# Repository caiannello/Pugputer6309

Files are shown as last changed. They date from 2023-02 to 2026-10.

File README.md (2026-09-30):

## Introduction
--------------------------------------------------------------------------------
```
WELCOME TO THE PUGPUTER 6309 PROJECT !!!

The Pugputer is a little labor of love, made as a tribute to the 
early home computers of the 1980's.  

It is based on the Hitachi HD63C09 CPU- an upgraded licensed clone of the
venerable Motorola 6809, and uses vintage parts where appropriate. 
(Except RAM chips, which are plentiful and affordable these days, and a modern 
microcontroller to handle SD card and GPIO.)

Projects in the Hardware directory: 
  (Using CADSOFT EAGLE 4.16r2)

  6309 CPU Card -       HD63C09P CPU, R65C51P2 UART, 1MB RAM, 32K ROM, RTC
                        (Mem expandable to 4MB) 
  Backplane -           Five card slots, tombstone style 
  V9958 Video -         Same graphics chip as the MSX 2+ home computer 
                        Optional OPL3 synthesizer module (YMF262)
  VIA_SD_PSUP -         SD Card, SPI, I2C, ADC, parallel port, and power supply.
  3 MB RAM Expans. -    Gives the Pugputer more memory than actual pugs. 
  all-in-one -          Combines all of the above on one 10.6" x 3.5" board

Projects in the Software Directory:  (All are work-in-progress, stay tuned.) 
  (Using LWTOOLS/LWASM 4.20 for the 6309 assembly stuff)

  6309 Extended Basic -   Microsoft, Walter K. Zydhek, Grant Searle,
                          Tom Circuit, and me
  boot -                  Minimal bootloader (Also unfinished, but coming soon!)
  Pugmon -                ML Monitor (Far from complete)
  Demos -                 graphics and sound examples in Assembly and BASIC

3D Models 
  (Using Trimble SketchUp MAKE 17.2.2555 for Windows 64-bit )
(Nice renders using Indigo Renderer by Glare Technologies)

```
## There's now a (vibe-coded) Emulator!
[Pugputer6309_Emulator](https://github.com/caiannello/Pugputer6309_Emulator)
It's got 1MB RAM, UART, 4K BIOS, FAT16 SD Card, RP2350-based Graphics Card, OPL3 Sound, DOS-like command shell, 
and on the SD card is a Text Editor, Assembler, Linker, and a version of Microsoft Extended BASIC 6809 that's 
been expanded with DISK support patterned on GW-BASIC, graphics and sprites, and the ON ERROR statement.
There's also some demos which play OPL3 music and demonstrate graphics capabilities.

On my PC, the emulator currently runs 92x faster than the actual hardware. Going to need to add throttling. 

You can interact with it from command prompt, a real Glass TTY at 19.2Kbaud, or if using the com0com NULL-modem 
driver for Windows, a terminal program. There's also a demo folder on the SD card that plays a couple VGM songs 
and demos some graphics. Excited to get the new utils/OS running on the real HW!  Also, note the lack of 
V9958 video. Going to go with the RP2350 instead, since it's much more capable and easy to use, and the V9958 
is getting more scarce and expensive. Using a modern MCU does bother me, but not as much as using an FPGA or
an inferior rare chip.

## Gallery

Graphics from SquareSoft's Seiken Densetsu 3 for Super NES ([Source code](https://github.com/caiannello/Pugputer6309/blob/main/Software/6309/Demos/mana_tilemap.asm))
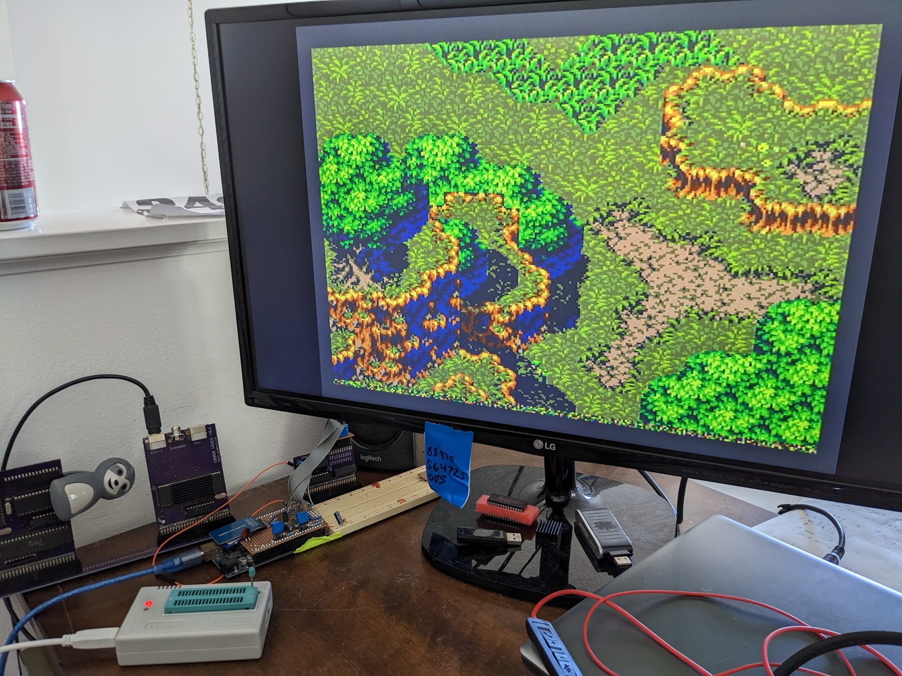
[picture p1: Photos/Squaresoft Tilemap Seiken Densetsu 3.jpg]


Microsoft Extended BASIC for 6809, modified by Grant Searle, Tom Circuit, and me ([Source code](https://github.com/caiannello/Pugputer6309/tree/main/Software/6309/MS%20Extended%20BASIC))
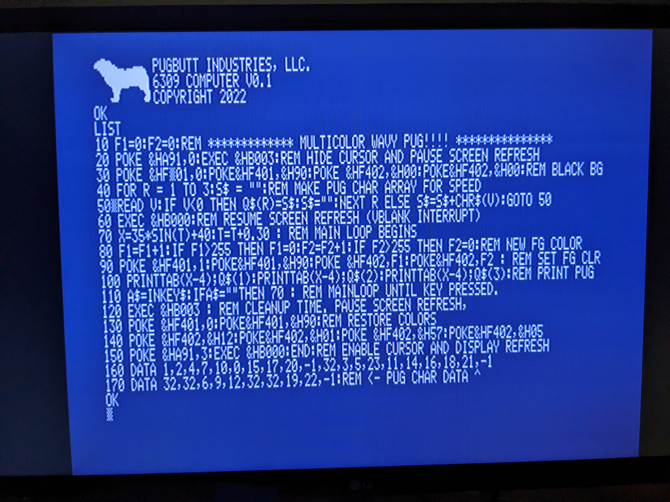
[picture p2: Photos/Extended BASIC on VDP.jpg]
basic


This one uses the library from the ancient [Motorola MC6839 FLOATING POINT ROM!](http://jefftranter.blogspot.com/2019/04/a-6809-single-board-computer-mc6839.html) ([Source code](https://github.com/caiannello/Pugputer6309/blob/main/Software/6309/Demos/mandelbrot.asm))
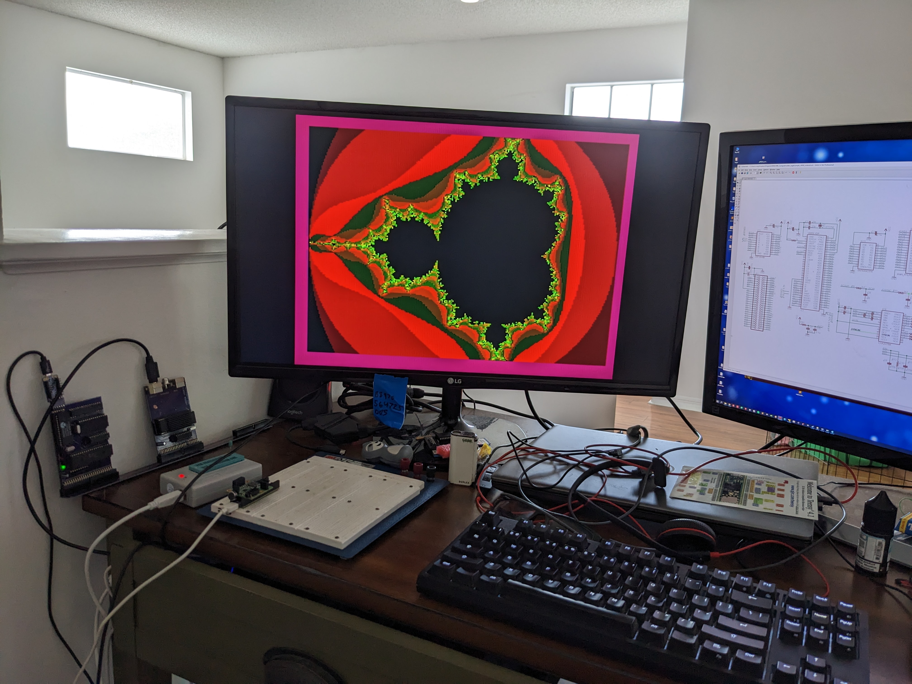
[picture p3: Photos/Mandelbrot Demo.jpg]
mandelbrot


[PugMon](https://github.com/caiannello/Pugputer6309/tree/main/Software/6309/Pugmon)
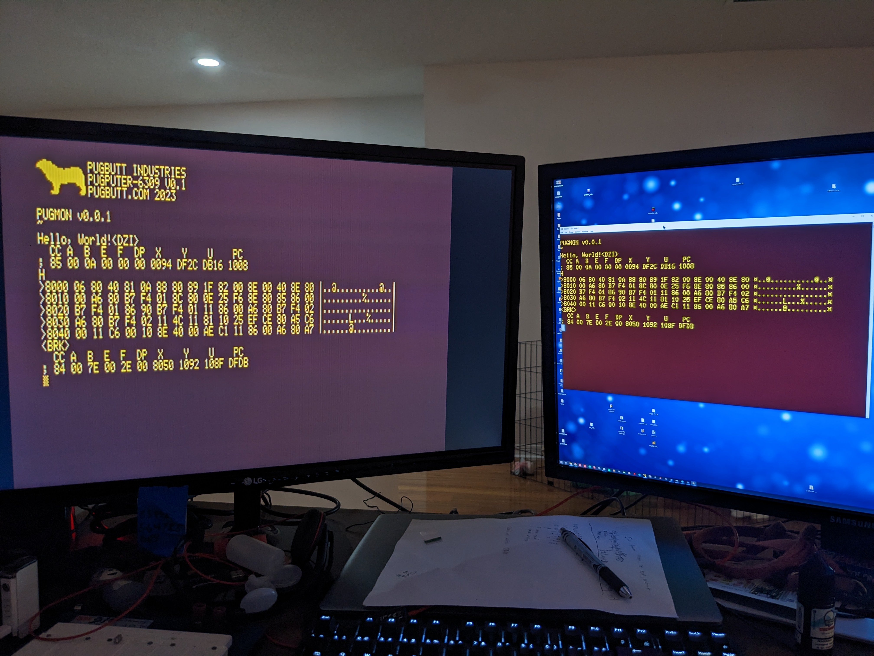
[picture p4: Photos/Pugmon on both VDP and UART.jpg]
pugmon


Lily from a local pond, converted to the V9958's high-color YJK mode using a Python utility. Please ignore my dog's toothpaste and "toothbrush". Please also ignore the ugly DRAM sidecar on the video card, I think the SRAM problem has been found. (I used a CMOS instead of a CMOS TTL latch.)  

([Source code](https://github.com/caiannello/Pugputer6309/blob/main/Software/6309/Demos/lily_highcolor_yjk.asm))([Conversion Utility](https://github.com/caiannello/Pugputer6309/blob/main/Software/dev_utils/image_conversion/conv_yjk.py))
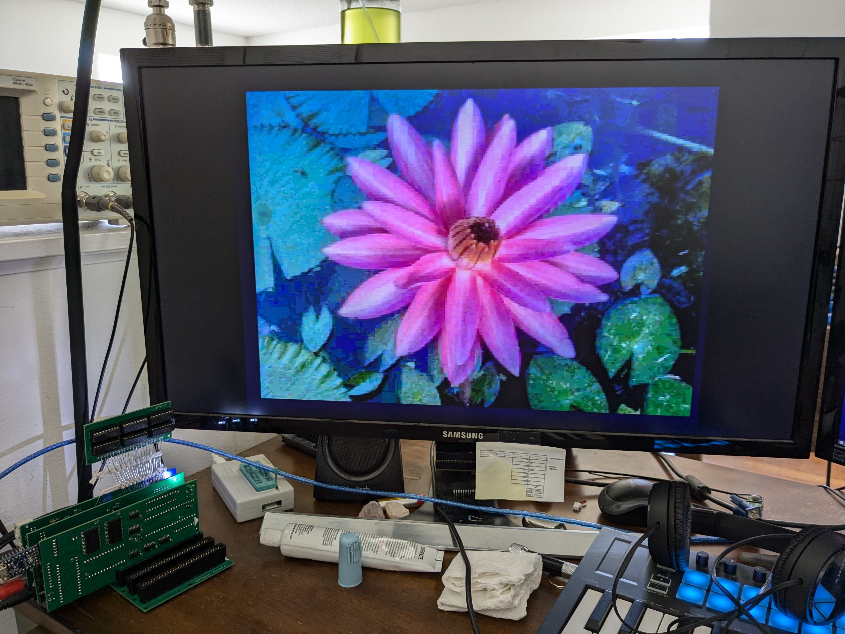
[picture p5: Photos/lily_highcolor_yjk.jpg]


Experimental Pugputer startup screen + jingle by ([Bisqwit](https://https://bisqwit.iki.fi/)!

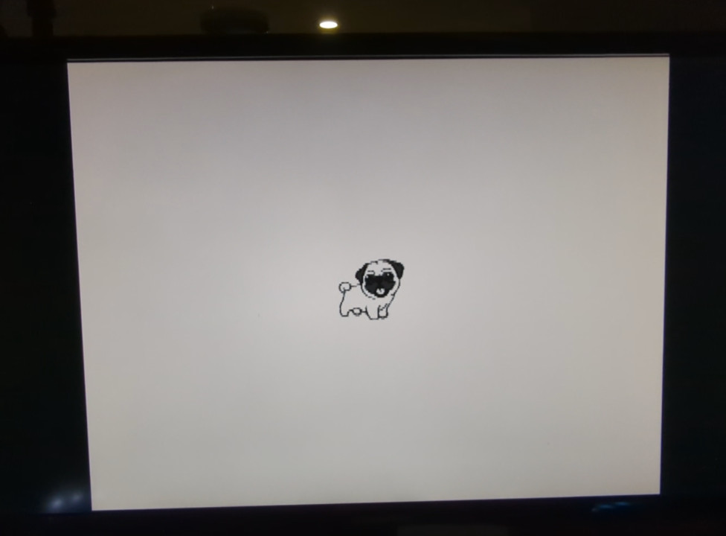
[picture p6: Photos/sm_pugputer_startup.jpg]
Watch Video


### CPU Card v2 (Card cage design)

CPU Card with 1MB RAM and UART
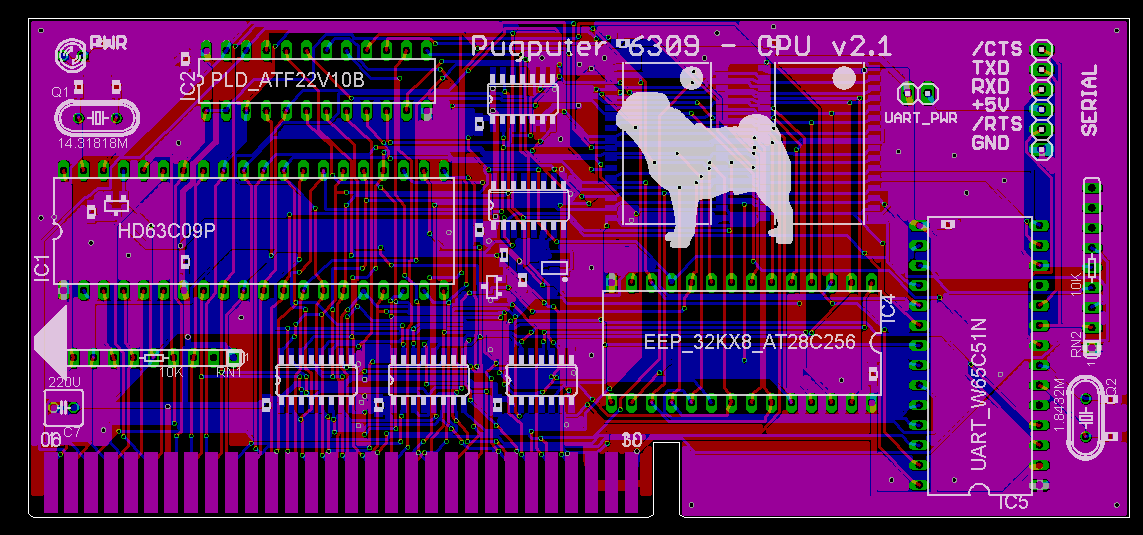
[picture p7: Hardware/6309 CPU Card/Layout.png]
layout


Backplane
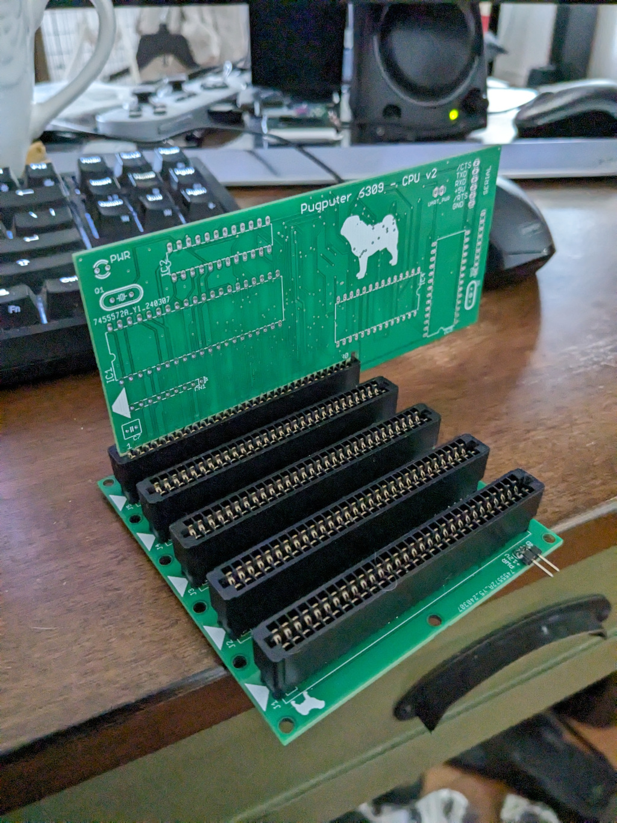
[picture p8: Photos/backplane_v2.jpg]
backplane v2


### All-In-One Motherboard

6309 CPU @ 3.57MHz, Serial Port, Real-time clock, 4MB RAM, SD Card, Arduino MCU, V9958 Video, OPL3 Sound  (Board size 11" x 3.5")
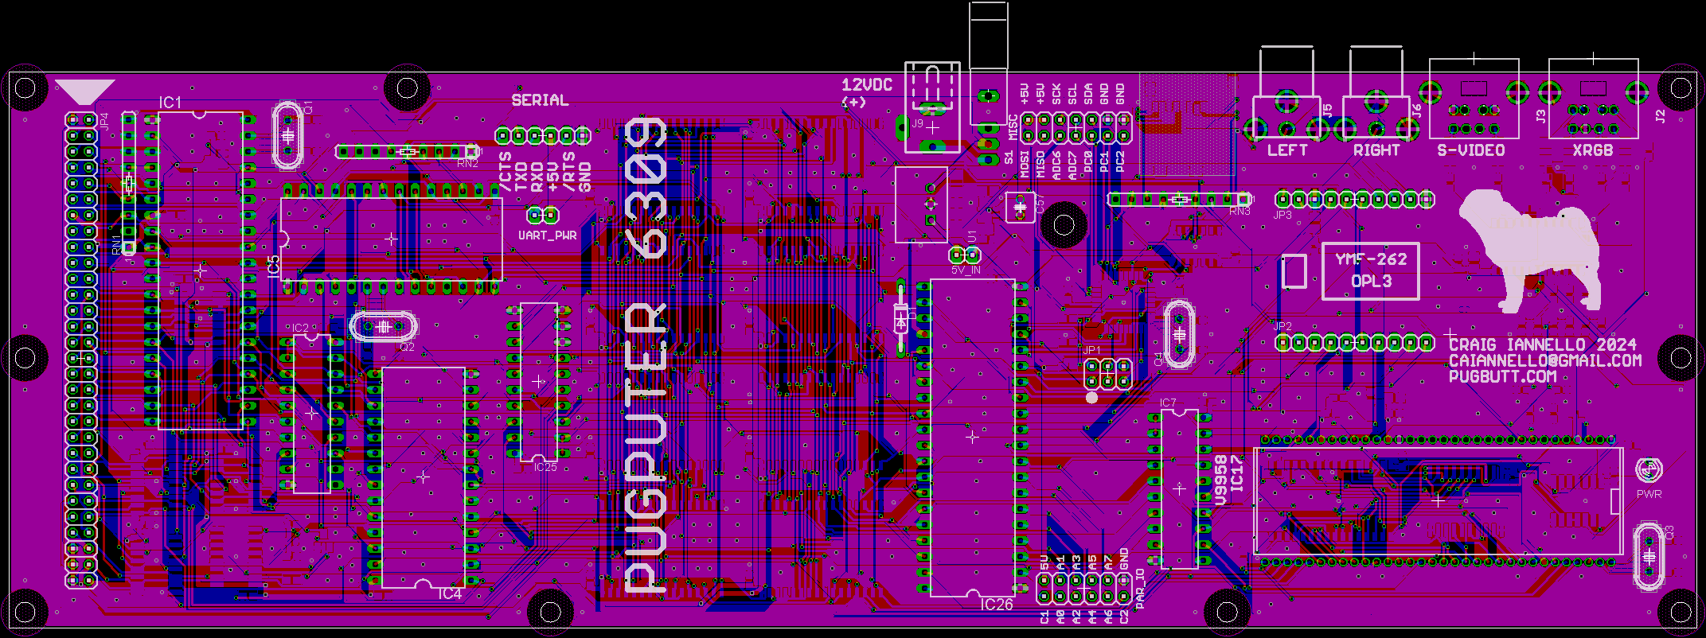
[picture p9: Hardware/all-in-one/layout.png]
layout

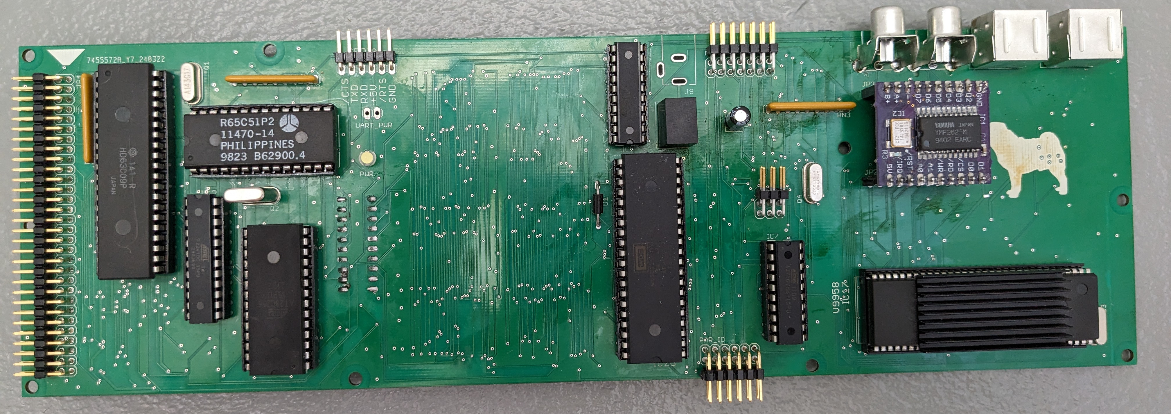
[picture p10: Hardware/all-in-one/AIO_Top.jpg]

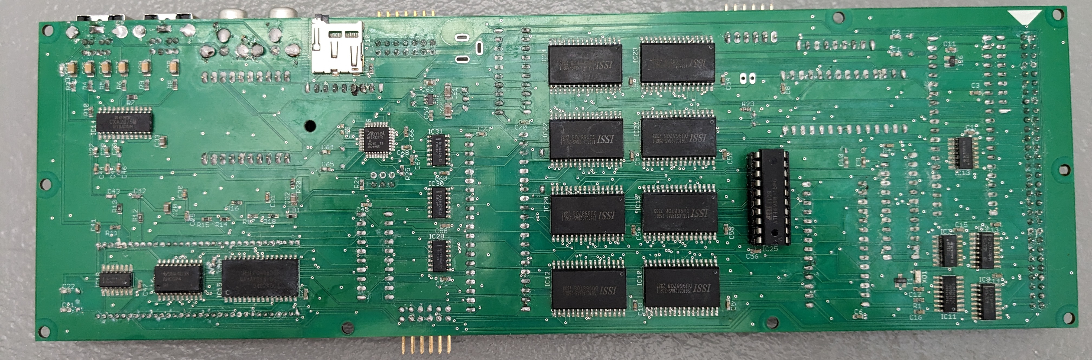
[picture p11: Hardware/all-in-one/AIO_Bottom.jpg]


### v0 System (All-in one keyboard design)

This system has smaller cards with pin headers and can lie flat inside a keyboard enclosure, but it only has 64K of RAM and no bank switching, and the backplane is expensive to fabricate because it is a 4-layer board.

The card in the middle in the below image is a prototype multifunction card. It comprises a Teensy 4.1 in a ZIF socket with a piggybacked audio card, connected to the backplane via the LV Parallel interface. The USB host connector of the Teensy is connected to the keyboard, but I hope to have some kind of USB hub, eventually. Also note, the backplane shown doesn't space the cards far enough to allow all five to be populated at once. This has since been corrected in the board design, and the total length is still shorter than the keyboard at 13.8 out of 14.125 inches.
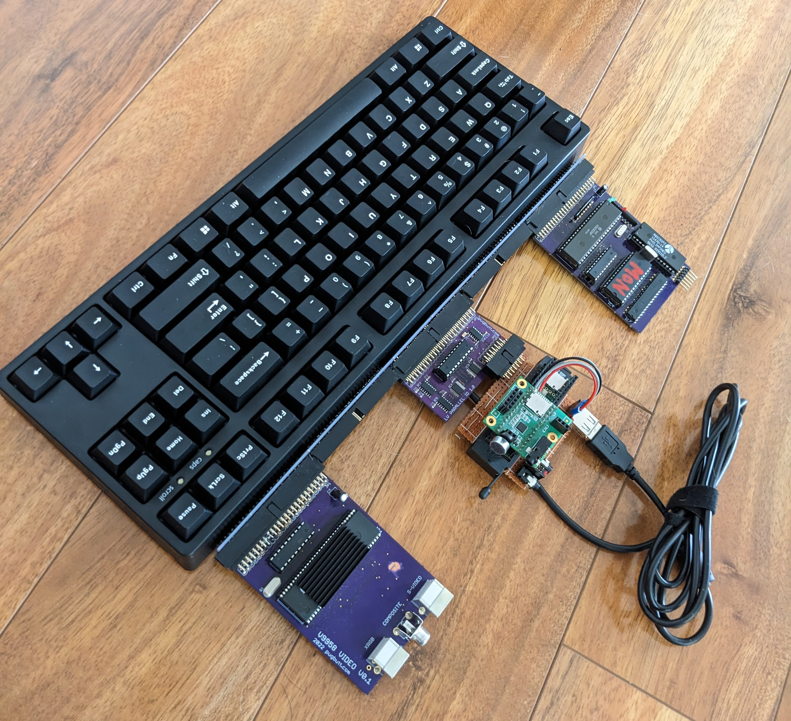
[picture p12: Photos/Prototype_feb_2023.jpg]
prototype


([Board designs](https://github.com/caiannello/Pugputer6309/tree/main/Hardware))
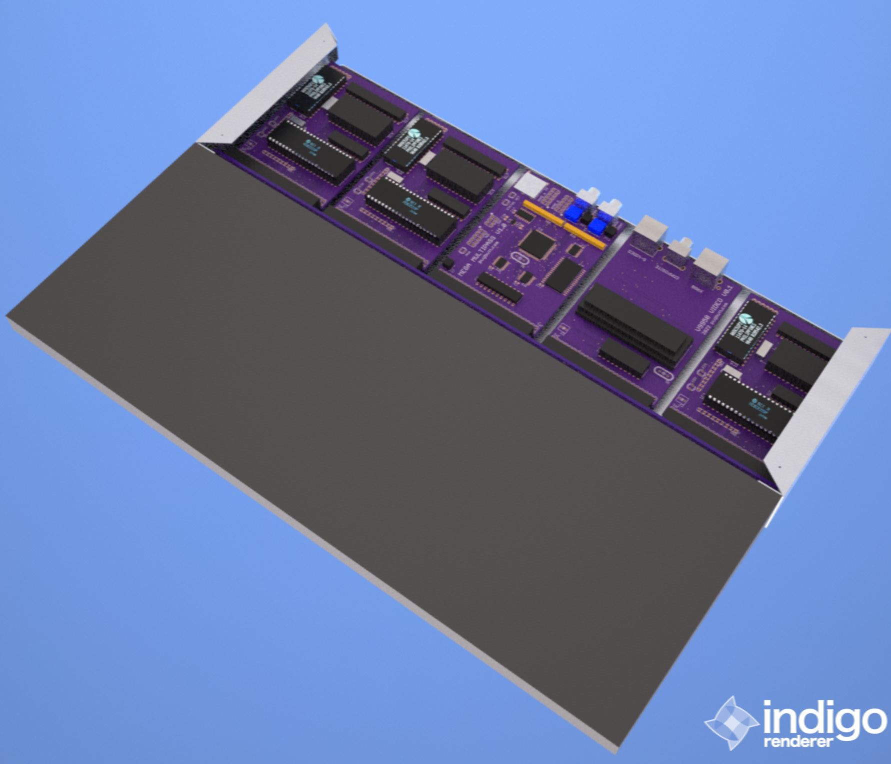
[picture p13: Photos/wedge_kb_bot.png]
bottom


Still working on a nice enclosure.. (I wish I had taken shop class in high school!) ([SketchUp Models](https://github.com/caiannello/Pugputer6309/tree/main/3D_Models))
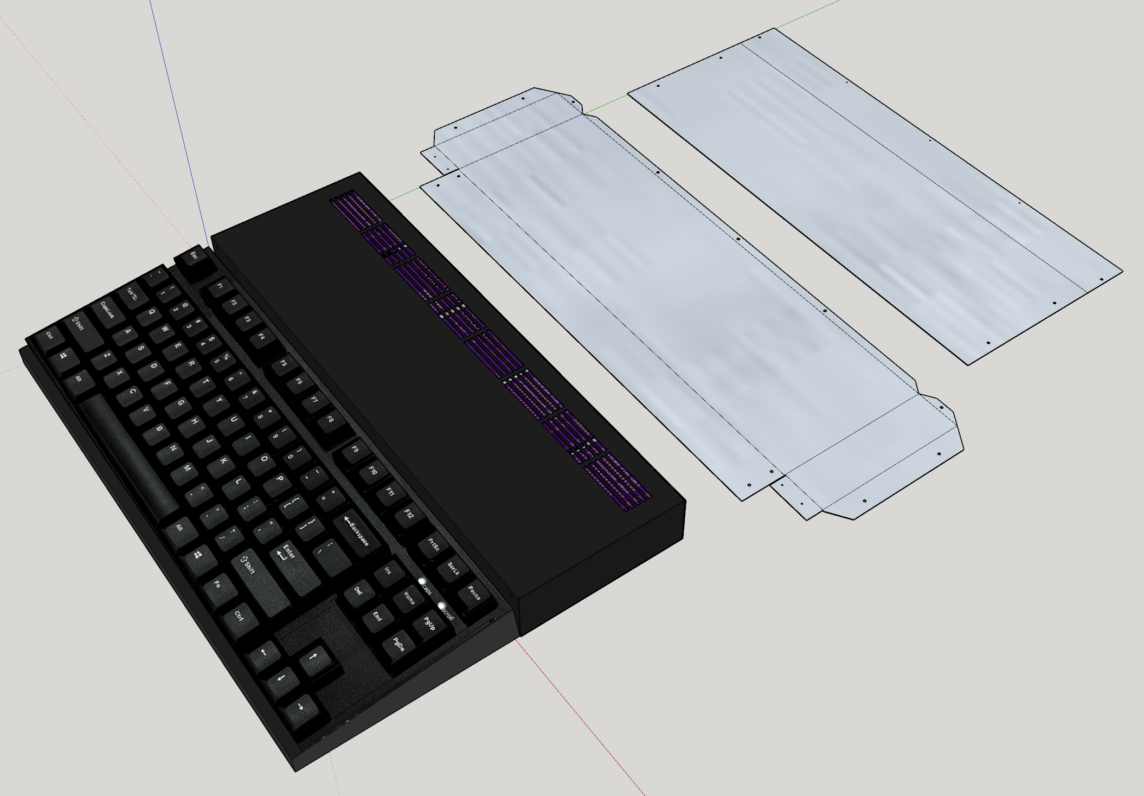
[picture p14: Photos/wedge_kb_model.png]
case design


## Contact

If you are interested in this project or MC6809 and HD6309 CPU's in general, I post sporadic updates about this project on [this facebook group.](https://www.facebook.com/groups/6809assembly), and can be reached there (Craig Iannello). It's really great as far as technical groups go in that people are respectful and friendly, unlike some forums where trolls circle new members like sharks. (I'm looking at you, AVR Freaks!) If you'd prefer email, the address is my github user name as shown above, at that giant search engine company with a name which starts with a G.

## Todo: Youtube Videos

Once this project is further along, I plan on making some demo videos and putting them on my [youtube channel](https://www.youtube.com/appliedcryogenics). In the meantime, there's some older projects on there, so it may still be worth a browse. 

## Todo: Modern VDP Replacement!

After choosing the Yamaha V9958 as my video chip and writing some code, I saw the prices on these vintage parts rising, and the number of listings dwindling. Also, I've decided it's not even that great of a chip. (Multicolor sprites are a major pain!) There's a lot of community efforts to emulate this whole family of chips (V9918, V9938, V9958) using a modern Raspberry Pi Pico! (But, like I said, though, I'm not terribly fond of these chips. I decided to try to use the Pi Pico to make something better... which resulted in...) 

## The PugVDP Project!!

[PugVDP](https://github.com/caiannello/PugVDP)

But, the attention-span is weak, and having already trash-talked the Yamaha VDP, I'll admit that this project only does text mode so far. 
...but it's a *really* nice text mode!




### Animated GIF showing increasingly-small semigraphics characters


^^ Still not a real graphics mode, though. Needs bitmaps, tilemaps, and sprites! My dream VDP would provide 80-column text and Super Famicom levels of tiles and sprites.

Wow, you're still reading all the way down here? <3 <3 THANK YOU!

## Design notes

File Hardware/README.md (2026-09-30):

```
PUGPUTER 6309 - Hardware
-------------------------------------------------------------------------------
The schematics and board artwork for this project were created using
Cadsoft EAGLE v4.16r2 Professional. 4.16r2 is old, but pretty nice, and it
seems to still work well in Windows 10, OSX, and Linux.

The freeware version of Eagle has limited board size and layercount, but all
boards are viewable. Editing may be another story. TODO: Learn Kicad?
-------------------------------------------------------------------------------
Projects in this directory:
6309 CPU Card V2      HD63C09P CPU, R65C51P2 UART, 1MB RAM, 32K ROM, RTC
V9958 Video Card      Same graphics chip as the MSX 2+ home computer + OPL3
Pico2_Video_Misc      RP2350B graphics card, replaces V9958 one.
VIA_SD_PSUP           Power supply, W65C22 VIA, MCU, SD Card, SPI, I2C, etc.
Backplane             Five card slots, tombstone-style
RAM Expansion         Gives the Pugputer more memory than actual pugs. (3 MB)
all-in-one            Combines all of the above into one 10.6" x 3.5" board
-------------------------------------------------------------------------------
```
layout
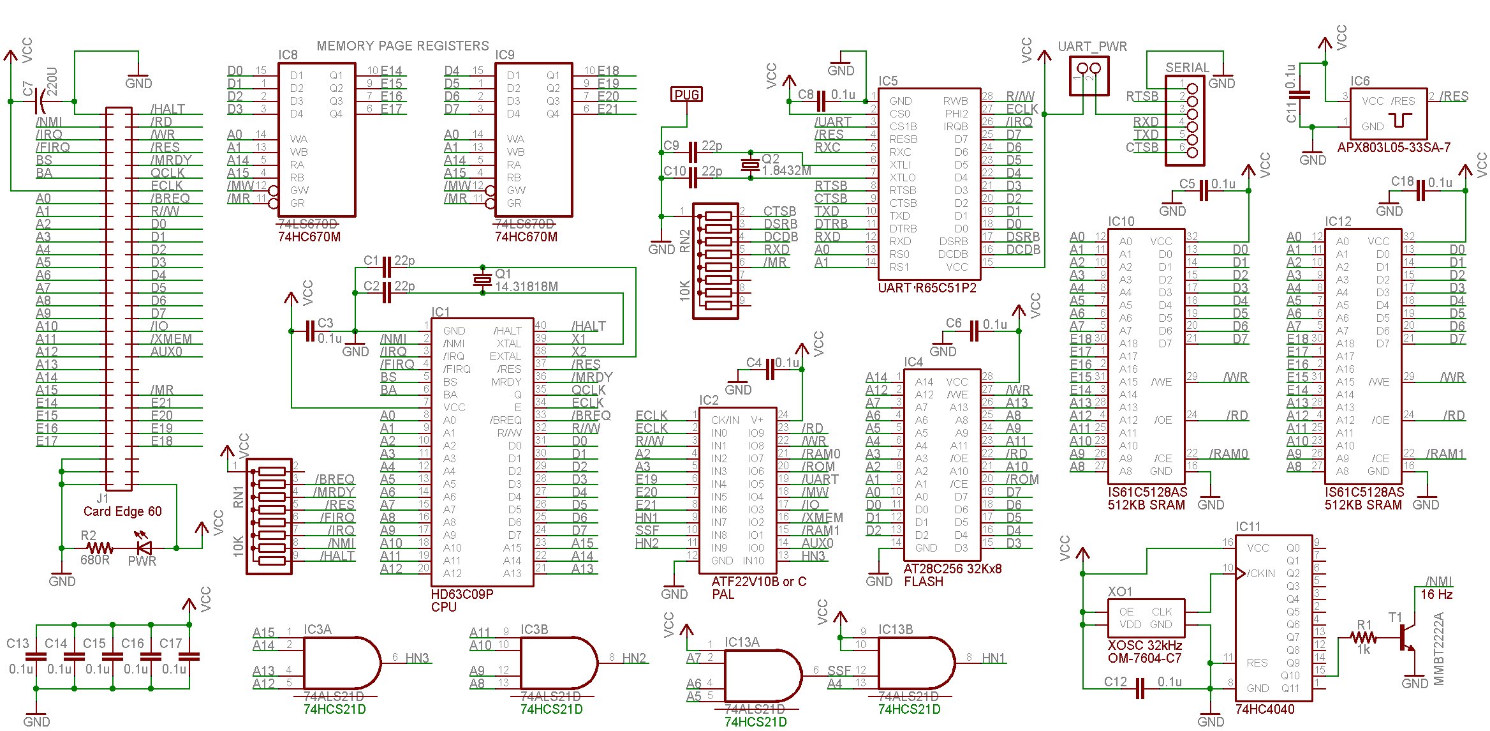
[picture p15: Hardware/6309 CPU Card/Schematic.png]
schematic


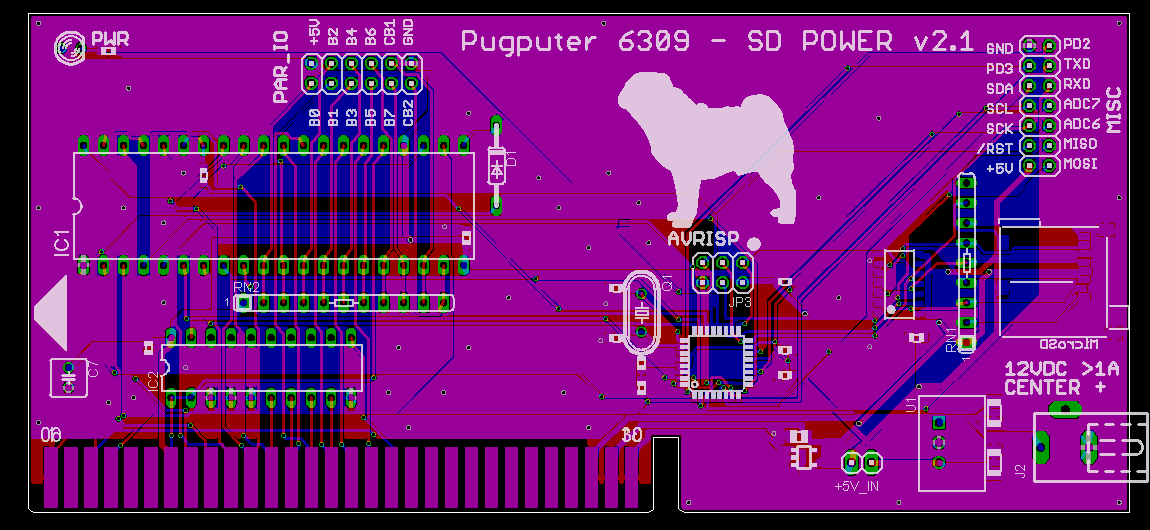
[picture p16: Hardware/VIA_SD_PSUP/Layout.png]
layout

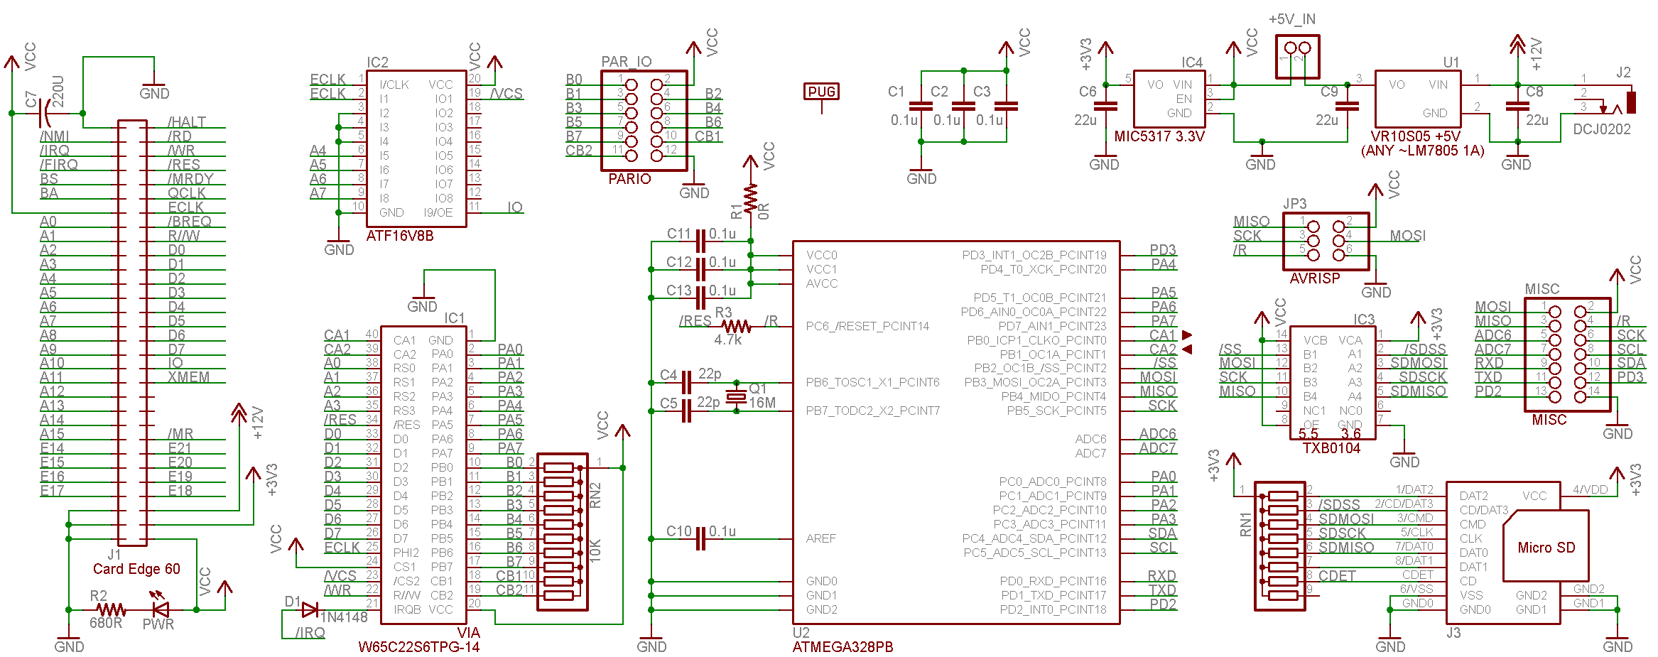
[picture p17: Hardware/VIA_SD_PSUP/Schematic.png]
schematic


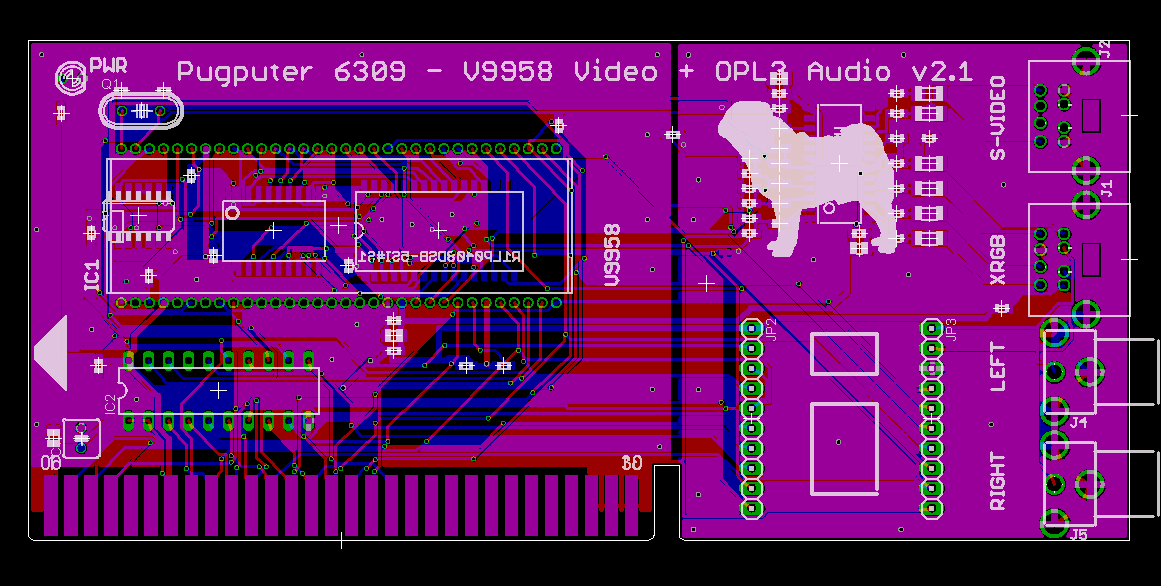
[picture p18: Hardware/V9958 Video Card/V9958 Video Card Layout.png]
V9958 Layout

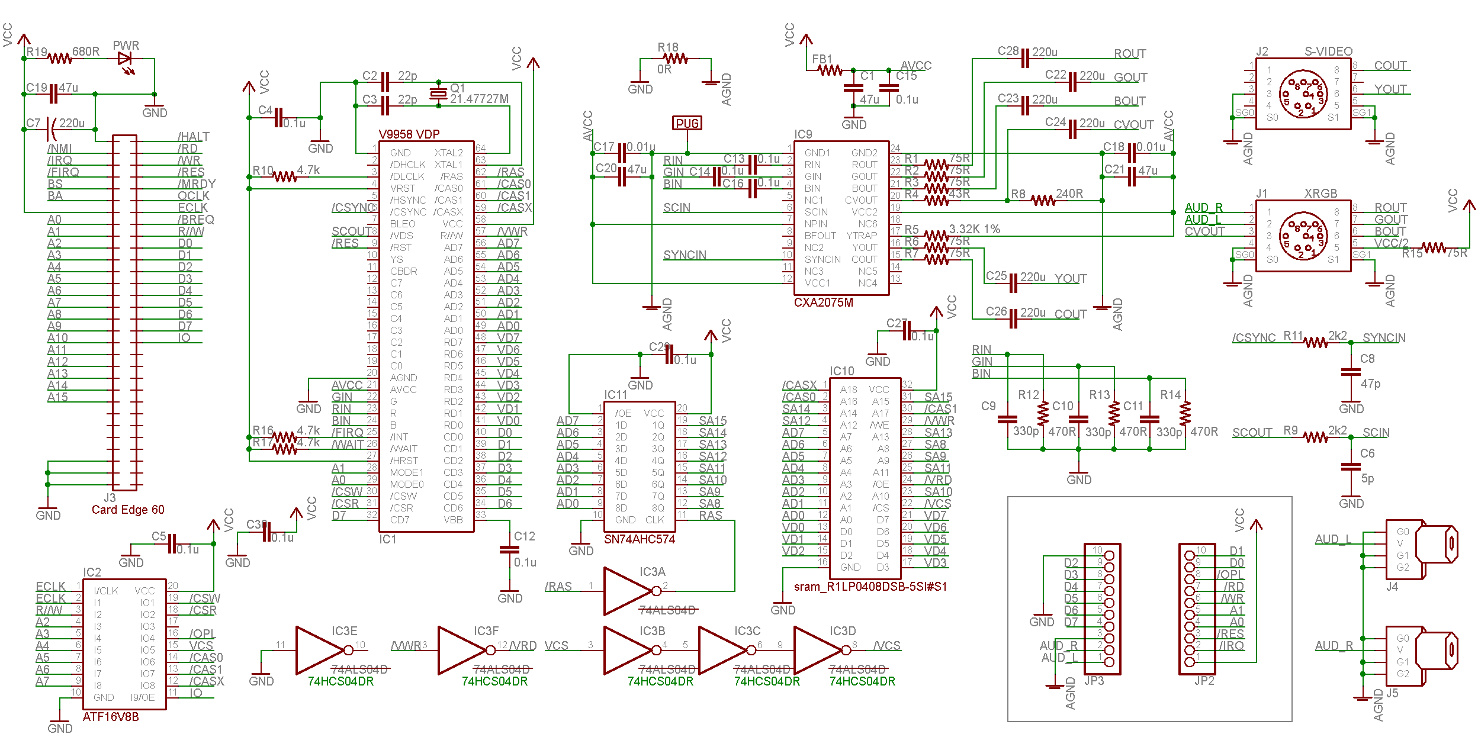
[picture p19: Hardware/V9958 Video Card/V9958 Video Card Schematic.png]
V9958 Schematic


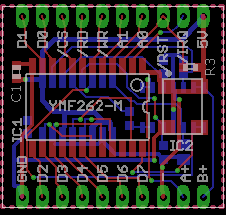
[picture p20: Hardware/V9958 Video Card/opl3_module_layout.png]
OPL3 Module


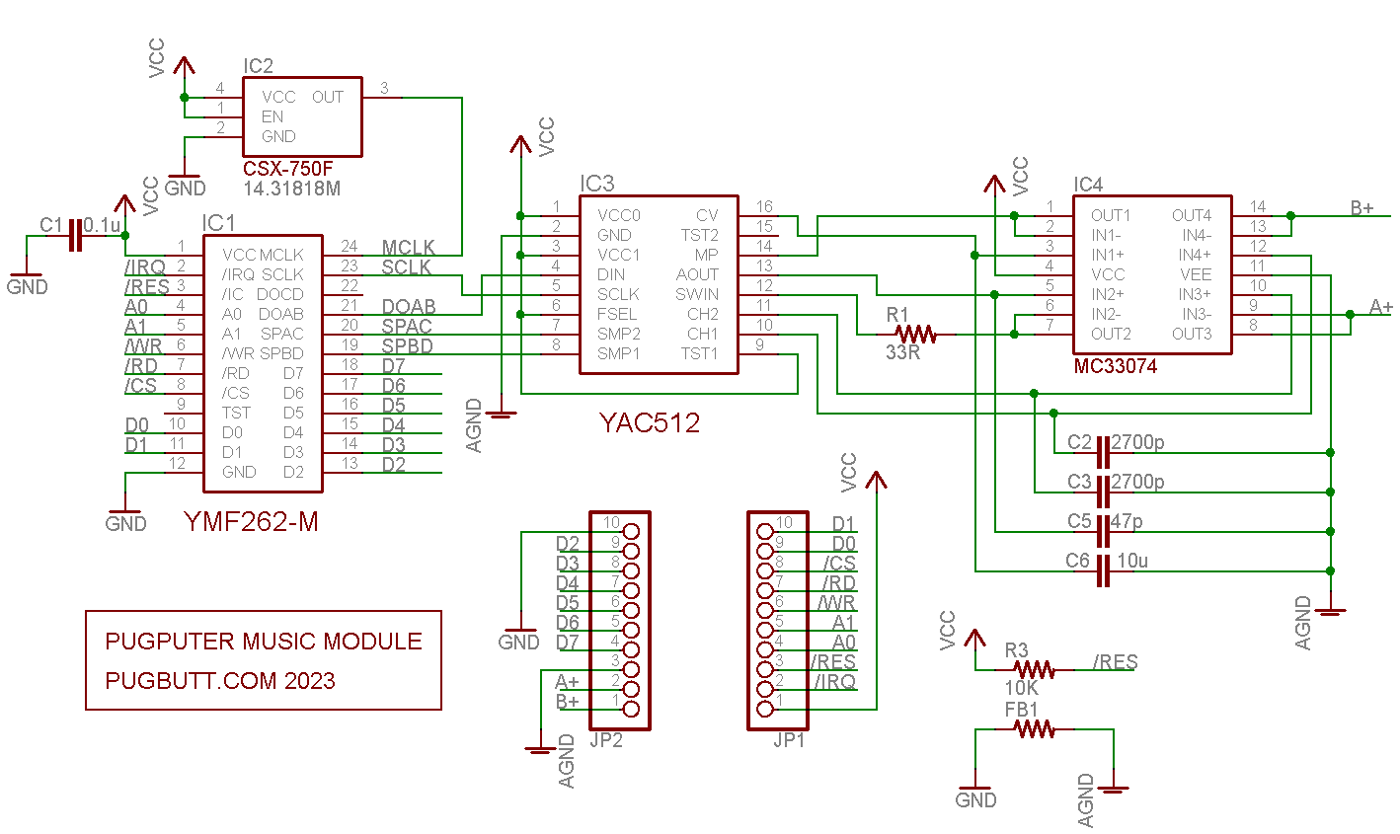
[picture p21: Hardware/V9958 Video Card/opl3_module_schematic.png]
OPL3 Schematic


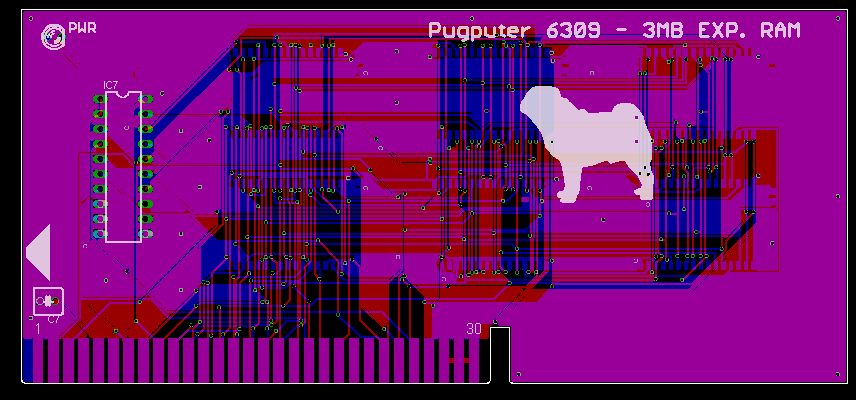
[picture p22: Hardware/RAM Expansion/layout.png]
3MB layout

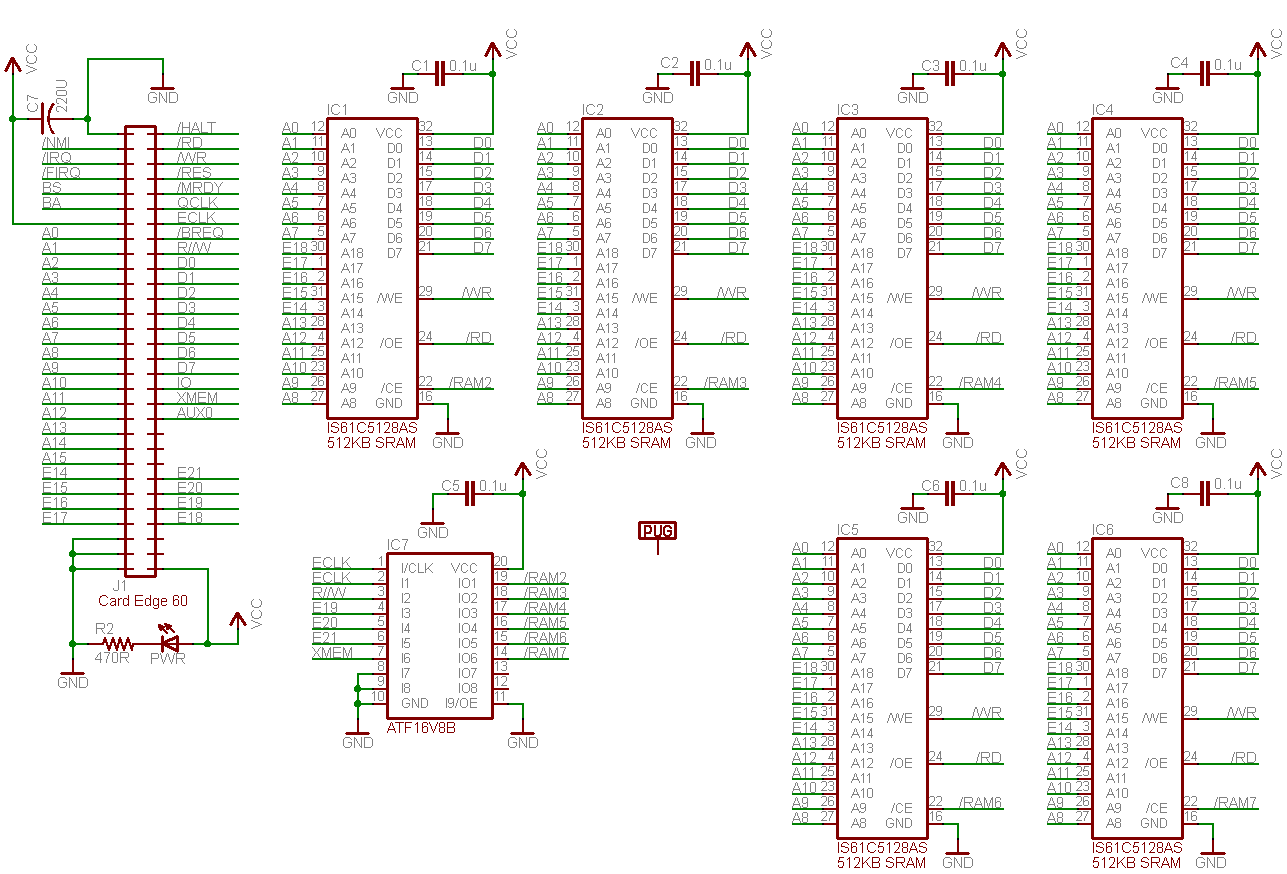
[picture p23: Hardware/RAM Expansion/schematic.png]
3MB schematic


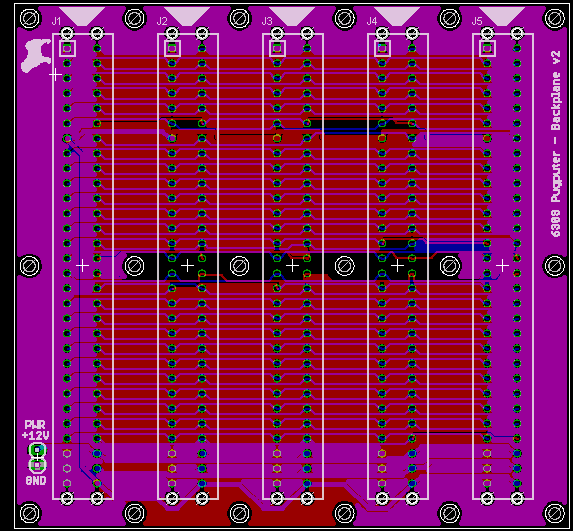
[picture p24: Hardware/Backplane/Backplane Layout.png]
layout

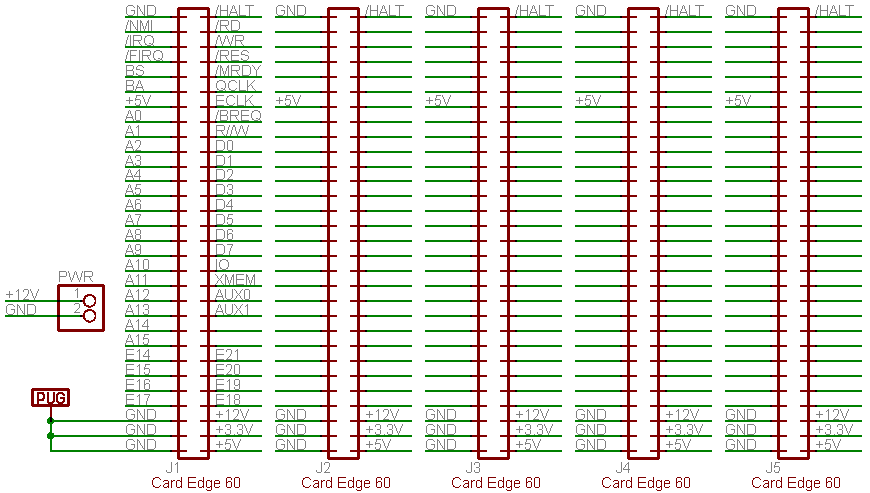
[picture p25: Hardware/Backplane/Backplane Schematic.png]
schematic


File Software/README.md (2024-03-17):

```
-------------------------------------------------------------------------------
PUGPUTER 6309 - Software and Firmware
-------------------------------------------------------------------------------

Note: All code, especially the parallel interface code, are works in progress.

The software is far enough along to validate the functions of the parallel 
interface cards and MCU services such as SD card, audio, keyboard, etc.,
but the API for these services is not yet done, so they are not yet usable
by the pugputer. I hope to add file handling to BASIC and Pugmon soon.

Contents

6309 		Extended Basic, bootloader, Pugmon, demos of sound and graphics

Arduino UNO	Allows an Uno to be connected to the Pugputer (via parallel IO
		card) to provide SD Card, SPI, PS/2 keyboard, and minimal (PWM)
		audio

Teensy 4.1	Allows a Teensy 4.1 to be connected to the Pugputer (via the
		LV Parallel IO card) to provide SD Card, SPI, USB, 
		USB Keyboard, real-time clock, GPIO, Gamepad connectors, 
		coprocessing, and professional-quality audio

-------------------------------------------------------------------------------
```

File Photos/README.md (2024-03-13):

kb wedge

```
The keyboard shown in the model can be found here:
https://smile.amazon.com/dp/B08B84VPN9

It is USB, so to use it with my project, I either have to use a 
microcontroller like Teensy, which has a USB host port, maybe find
some kind of adaptor, or I have to take the KB apart, hack out the 
electronics, and wire up the matrix directly. I am leaning towards
using the Teensy for the time being, and the included Teensy source
shows keypresses from connected USB keyboards.

A much easier way is to get a keyboard that has a PS/2 interface. That has
just two-open-drain signal lines, clock and data, similar to i2c. 
It's easy to interface PS/2 KB's to even the most minimal 
microcontrollers.
```
backplane v2
bottom
basic
mana
mandelbrot
pugmon

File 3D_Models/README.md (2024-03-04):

```
The 3D Models in this directory are created using 
Trimble's SketchUp Make v17.2.2555 64-bit for Windows. 

Path-traced nice renders are made using the 
Indigo Renderer by Glare Technologies through the 
Skindigo addon for SketchUp.

```
## v2 (Card cage design)
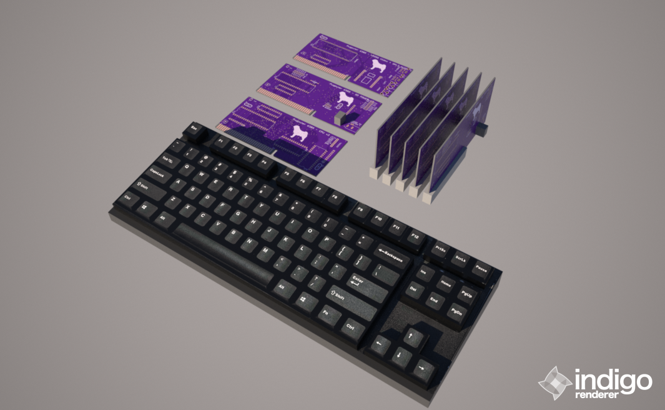
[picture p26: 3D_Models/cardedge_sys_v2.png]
Cardedge system


## v0 (Flat design with pin headers)
Origami case

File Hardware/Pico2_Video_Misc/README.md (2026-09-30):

## RP2350B (Raspberry Pi Pico 2) Video Card

This is the video card implemented by the emulator, and it's hugely more performant than the V9958 predecessor. 
I have yet to add the OPL3 module to this card, but that will probably happen eventually. This card is based 
on an Olimex RP2350-PICO2-XXL, and a cheap HDMI breakout board off Amazon. (Going to need to get a real part 
number on that part eventually. Basically, pin 0, at the top-left is GND, and after that its HDMI pins 1 
through 19.

For a writeup on the current capabilities of this card, see [Pugputer6309_Emulator - Video card readme](https://github.com/caiannello/Pugputer6309_Emulator/tree/main/vidcard)

## Video Card Layout and Schematic

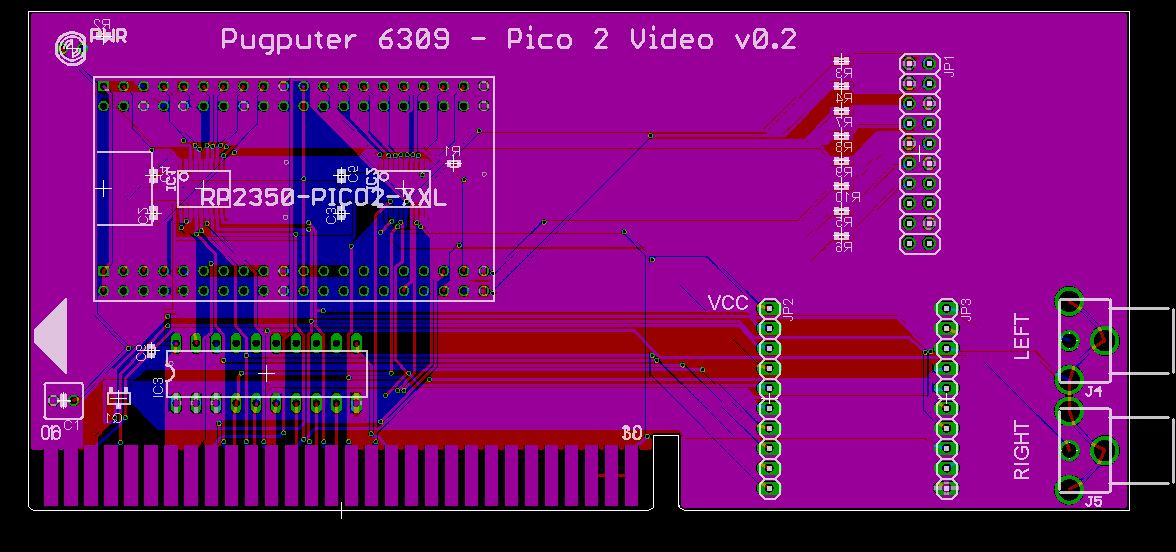
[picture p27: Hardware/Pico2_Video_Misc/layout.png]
Layout


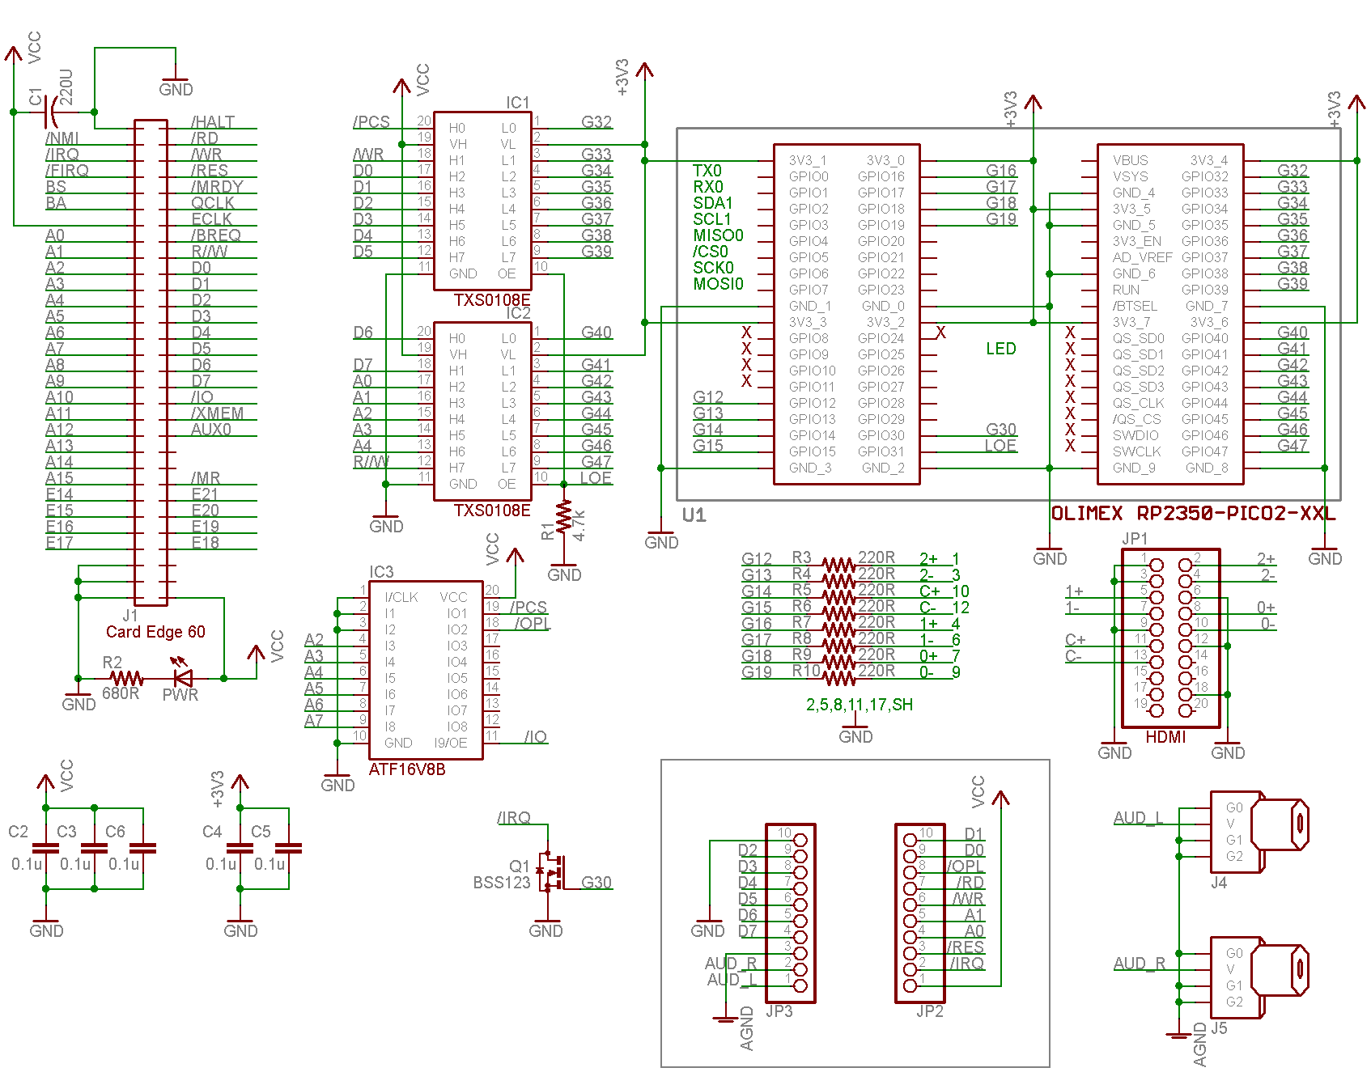
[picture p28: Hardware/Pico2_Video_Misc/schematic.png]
Schematic


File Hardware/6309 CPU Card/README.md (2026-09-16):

## 6309 CPU Card v2

```
2025-02-15 UPDATE:

V2.1 moves the card-egde connecter fingers further from the board edge to facilitate gold-plating of the connector.

```

```
2024-03-01 UPDATE:

Added a new v2 CPU card. It has the same HD63C09 clocked at 3.57 MHz, 32K Flash
ROM, and serial UART, but it adds 1 MB SRAM, expandable to 4 MB, and a real-
time clock interrupt.

Rather than a pin header connection to the backplane, this one uses a classic 
60-pin card-edge connector similar to a Nintendo Famicom cartridge.

Moved previous version to past_revs/ subfolder. 
```
layout

schematic

## Memory Map v2
```
  name      strt - end     size     notes
  ----      -----------    ----     -----
  MEM0      0000 - 3fff    16384    Mem sect 0 (a14 - a21 from bank reg. 0)
  MEM1      4000 - 7fff    16384    Mem sect 1 (a14 - a21 from bank reg. 1)
  MEM2      8000 - bfff    16384    Mem sect 2 (a14 - a21 from bank reg. 2)
  MEM3      c000 - efff    12288    Mem sect 3 (a14 - a21 from bank reg. 3)
  ROM       f000 - feff    3840     Fixed ROM  (bootloader)
  IO0       ff00 - ff0f    16
  IO1       ff10 - ff1f    16
  IO2       ff20 - ff2f    16
  IO3       ff30 - ff3f    16
  IO4       ff40 - ff4f    16
  IO5       ff50 - ff5f    16
  IO6       ff60 - ff6f    16
  IO7       ff70 - ff7f    16
  IO8       ff80 - ff8f    16
  IO9       ff90 - ff9f    16
  IO10      ffa0 - ffaf    16
  IO11      ffb0 - ffbf    16       W65C22 VIA (SD Card, SPI, KB, GPIO)
  SIO0      ffc0 - ffc3    4      
  SIO1      ffc4 - ffc7    4      
  SIO2      ffc8 - ffcb    4      
  SIO3      ffcc - ffcf    4      
  SIO4      ffd0 - ffd3    4        
  SIO5      ffd4 - ffd7    4        
  SIO6      ffd8 - ffdb    4        
  SIO7      ffdc - ffdf    4        
  SIO8      ffe0 - ffe3    4        Music Chip YMF262 (OPL3)
  SIO9      ffe4 - ffe7    4        Video Chip V9958
  SIO10     ffe8 - ffeb    4        Serial UART R65C51P2
  SIO11     ffec - ffef    4        Memory Bank Regs 0...3
  intvec    fff0 - ffff    16       Fixed ROM (interrupt vectors)
```
## Memory Paging Scheme
```
Two 74LS670 chips are added to the design which provide four writable bytes at
CPU addresses $ffec - $ffef. These act like dual-ported RAMs and enable each 
of the four 16KB sections of the CPU address space to be independently mapped a
different 16KB page of physical memory (up to 4MB.)

CPU Address lines A14 and A15 select which register is active, which then 
provides extended address bits E14...E21 to the system. These are combined with
CPU address bits A0...A13 to form the final 22-bit physical address.

The initial state of the registers is unknown on startup and must be 
initialized before any RAM access should occur. Initially, these are mapped to
the first four pages of physical memory by setting the bank registers as 
follows:

Sect   CPU Adrs    22-bit physical Adrs     Bank Reg (E21...E14)
0      $0000       %0000000000000000000000  $00
1      $4000       %0000000100000000000000  $01
2      $8000       %0000001000000000000000  $02
3      $c000       %0000001100000000000000  $03

```
## Expanded Memory
```
For memory addresses beyond the onboard 1 MB, one or more bits E20...E21 will 
be set. The PAL will not select onboard RAM and will instead set XMEM bus 
signal. This can be used to select memory expansions.
```
## Real-Time Interrupt - Notes
```
The real-time interupt causes an /NMI to happen at a rate of 16 Hz.

The /NMI input is edge-sensitive, unlike /IRQ which is level sensitive, so it
should be OK that the implementation will keep /NMI low for half the time, as
long as we dont someday need to share /NMI.

The /NMI ISR will simply count ticks, which is enough to allow tracking of
date and time. There's no battery backup, so current date and time must be
provided on each powerup, either manually or via network. 

There's a design decision to be made regarding timekeeping: Rollover. With 16
ticks per second, the count gets big fairly quickly. If we kept count as a 
16-bit value, it would roll over every 1.14 hours! (Not good enough for dates.)
A 32-bit counter would roll over every 8.5 years, which is better, but what if
we wanted a high-reliability hobbyist retrocomputer? A 64-bit counter would 
give us 365 million centuries! Aww yeah baby.

Despite the above rambles, date and time aren't even the main reason the 
real-time feature was added:

In the use-case I've been running up against with v0 is that when there is just
a CPU card being used with a serial terminal. A timer is needed to properly 
differentiate between certain key presses. For example, when escape is pressed,
a single 0x1b character is sent to the UART, but pressing cursor-up sends a 
sequence of three characters, starting with that same code: 0x1b, '[', 'A'. 
Most terminals use a timer to distinguish between single escape characters and
ANSI escape sequences. I didn't want to implement this timeout with a software
busy loop, so work began on CPU card rev 2. There's not enough room on the 
board for dedicated clock/timer chip such as the DS1287 or W65C22, so I went 
with this simpler option.
```
## Address Decoding Notes
```
These are thoughts about how to go about implementing the memory map on the 
system and programming the PAL. Some of this is implemented with discrete 
logic on the CPU card because the PAL doesnt have enough inputs to handle 
everything alone. The actual implementation is in the cpu_pld.PLD file,
which is loadable in WINCUPL for simulation and conversion into a bitstream
for PLD programming.

# Discrete combinatorial logic to help onboard PAL

hn3 = a15 & a14 & a13 & a12                # high adrs nybble == $f
hn2 = a11 & a10 & a9 & a8                  # next adrs nybble == $f
ssf = a7 & a6 & a5
hn1 = ssf & a4                             # next adrs nybble == $f

# Inputs to onboard PAL

eclk, r//w, hn3, hn2, hn1, ssf, e21, e20, e19, a3, a2

# Outputs from onboard PAL

/rd   = !eclk | !r//w                      # bus: memory read
/wr   = !eclk | r//w                       # bus: memory write
/io   = !hn3 | !hn2 | hn1                  # bus: IO select
xmem  = !hn3 & e20 | e21                   # bus: expansion mem select
/ram0 = hn3 | e20 | e21 | e19              # onboard: ram chip 0 select
/ram1 = hn3 | e20 | e21 | !e19             # onboard: ram chip 1 select
/rom  = !hn3 | hn2 & !hn1                  # onboard: ROM select
/mapw = !io | !ssf | hn1 | !a3 | !a2       # onboard: bank reg. write
/uart = !io | !ssf | hn1 | !a3 | a2        # onboard: UART select

# outputs from PALs on other cards:

/v9958  = !io | !a7 | !a6 | !a5 | a4 | a3 | !a2   # ffe4 - ffe7  Video Card video chip
/opl3   = !io | !a7 | !a6 | !a5 | a4 | a3 | a2    # ffe0 - ffe3  Video Card music chip

/via    = !io | !a7 | a6 | !a5 | !a4       # ffb0 - ffbf  W65C22 Versatile Interface Adaptor
                                           # (SPI, I2C, SD card, KB, gamepad, wifi, etc.)
```

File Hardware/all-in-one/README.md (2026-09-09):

```
PUGPUTER 6309 - All-In-One Motherboard
-------------------------------------------------------------------------------
This board is combination of all existing Pugputer 6309 circuit cards.

WARNING: Since some of these cards haven't yet been tested, I put the chances
of this big board needing 1+ bodges at around 75%  :D

Features
  10.6" x 3.5" size
  Voltage regulators - +12VDC in, +5VDC & +3.3VDC out
  HD63C09 CPU + 14.31818 MHz crystal (3.57 MHz bus clock)
  4 MB SRAM
  32 KB FLASH
  Real-time clock oscillator
  Serial UART
  WDC VIA + Atmega328 - SD Card, parallel port, misc analog/digital I/O
  Yamaha V9958 Video Display Processor - S-Video and XRGB output
  Yamaha YMF-262 - OPL3 music synthesizer
  60-pin bus connector

See the V9958 Video Card folder for the design files of the music synth module.

-------------------------------------------------------------------------------
```
## Populated prototype! Let the laborious clean-up and bring-up commence!
top
bottom
## TRAGEDY STRIKES! 
I put the +5V voltage-regulator on the board BACKWARDS, and sent +12V into the +5V RAIL!! 
Something apparently got fried. (I was so disappointed, I set the board aside,
and I haven't had the nerve to try to troubleshoot what remains. Might be easier to just populate 
a whole new board. $$$ :( But, having decided to replace the V9958 in the Pugputer with a modern 
replacement, that may never happen. )

## Layout and Schematic
layout
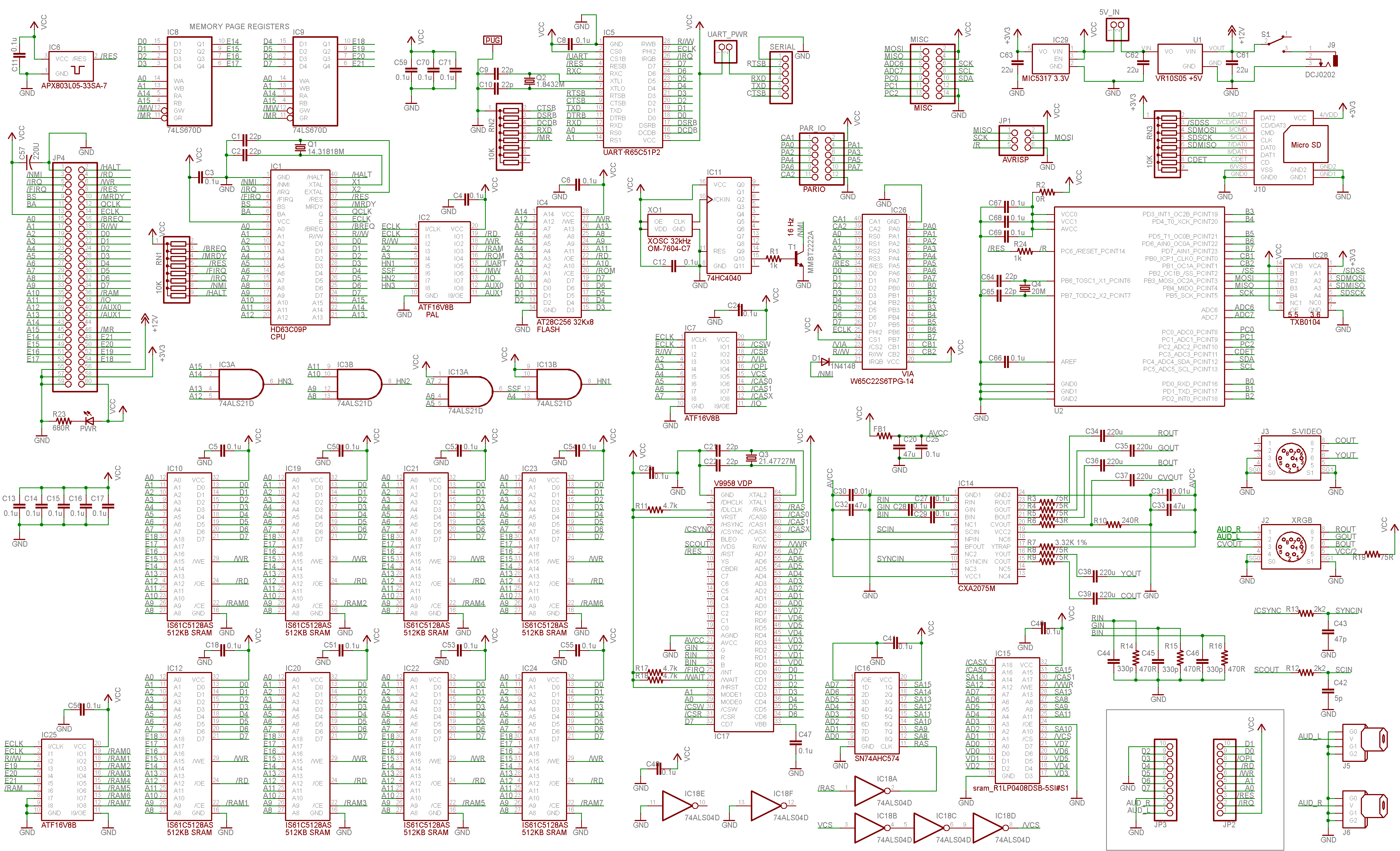
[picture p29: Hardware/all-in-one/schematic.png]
schematic


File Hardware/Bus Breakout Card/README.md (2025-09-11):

## Bus Breakout Board
```
This card is just a GAL for decoding and brings out most of the bus on a 50-pin header for use in prototyping.

Currently, the address for the main decoded /CS is $FFD0 ... $FFEF.

```

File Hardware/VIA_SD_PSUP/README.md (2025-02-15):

## Power, SD Card, GPIO
```
This card contains a W65C22 Versatile Interface Adaptor (VIA) which has some
timers, two 8-bit GPIO ports (PORTA and PORTB), and some handshaking lines.

PORTA connects to an ATMEGA328P MCU which provides SPI, I2C, SPI SD Card, and 
misc analog/digital IO. Several of these signals are brought out to a pin 
header which should allow connecting various game controllers, sensors, 
PS/2 keyboards/mice, AVRISP pod, etc.

PORTB and its handshake lines are brought out to a separate pin header as
a ready-to-use parallel port.

This board also has a barrel connector for supplying 12VDC to the system,
as well as voltage regulators to supply 5V and 3.3V to the system. The 5V
regulator pinout matches the old school LM7805 linear regulator, but I
opted for a modern switching replacement. The exact model isn't important, 
but it should be able to supply at least one amp.
```
layout

schematic

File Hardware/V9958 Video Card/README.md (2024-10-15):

## V9958 Video Card

This is the same Yamaha graphics processor that is used in the MSX 2+ line of home computers. It is a descendant of the TI V9918 VDP which was used in the TI-99/4A home computer and the ColecoVision game console from the early 1980's. A CXA2075M composite encoder chip is used to provide S-video and composite outputs. The picture quality is decent, though there are some very faint 'jail bars' in composite mode.

## Heads Up!

Even though this design doesn't deviate much from the (working) V1 board, my prototype had timing problems with the SRAM! I ended up having to solder up a daughterboard with six DRAM's on it before she started working. In retrospect, I think the problem was that I used a 74AHC574 (CMOS) for the latch rather than a 74AHCT574 (CMOS TTL) . I need to verify that, since the DRAMS are getting hard to find. 

## Wishlist

The V9958 Video Display Processor is starting to get more scarce, and the price is up to $40+ a piece now, and rising. The kind folks on the MSX Facebook Group have suggested the TN-VDP Tang Nano 20K project, which offers an FPGA-based replacement of this chip. I haven't put any hardware out yet, though, so I'm not married to V9958 compatibility, and I have a strong suspicion that a single Raspberry Pi Pico W could replace both the video card and the VIA card and maybe do WLAN too?

I have a Pimaroni "Pico Demo" board which does 15-bit RGB VGA, stereo sound, and SD card! I think I'd need to give up some color depth in order to allocate a bus interface, but I don't know if the Pico has enough oomph in its PIO's to handle so many features at once? If someone has the know-how to weigh in on this possibility and is willing to sketch out a bus interface and some pseudocode, I would be very grateful! I'm at caiannello at rhymes-with-moogle-pot-calm.  <3

## Video Card Layout and Schematic

V9958 Layout

V9958 Schematic

## OPL3 Audio Module

There's enough empty space on the video card to add this little music synthesizer module. The chips are one [Yamaha YMF262](https://www.polynominal.com/yamaha-opl3/) FM synthesizer, a YAC512 Stereo DAC, and an MC33074 buffer amplifier. There's some demos in the software demos section which play some of my favorite VGM tunes, and it sounds very good to me besides a very faint whine in the background which reminds me of the old Soundblaster days. Might need to find a way to filter that. :)

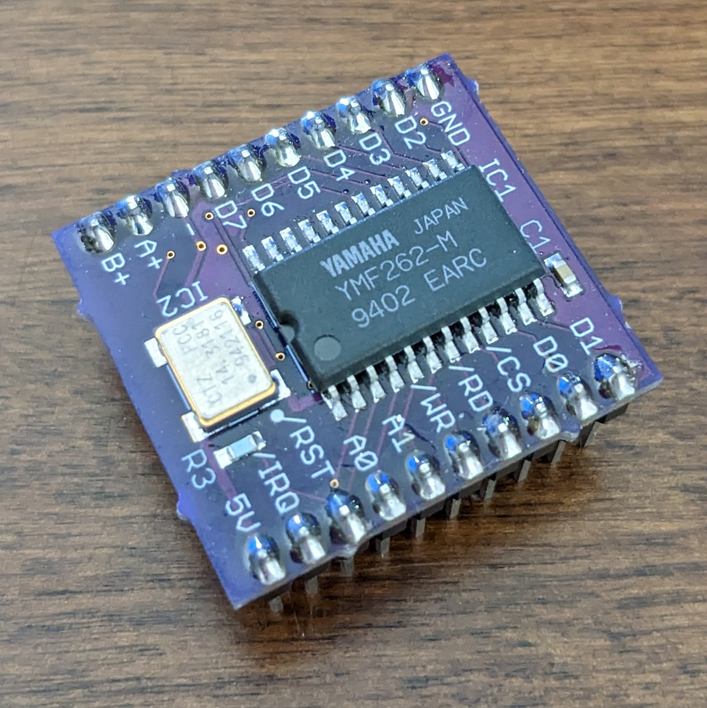
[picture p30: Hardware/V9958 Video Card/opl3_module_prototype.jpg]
OPL3 Module


OPL3 Schematic

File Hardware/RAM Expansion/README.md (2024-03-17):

## 3 MB RAM Expansion

### Gives Pugputer 6309 more memory than actual pugs.

3MB layout
3MB schematic

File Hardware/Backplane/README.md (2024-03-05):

## Backplane v2
```
This is a backplane for use with Pugputer v2, based on card edge-connectors
instead of pin headers. It is 3.7" x 3.5".

The connectors are 0.1" pitch, 60-pins, which I think is the same as the
cartridge slot on the original Nintendo Famicom.

Signals are straight passthrough for each pin; there are no swapped signals.
Power traces are wider (24 mil) to carry more current, and all 20 ground
pins are connected to a common ground plane for the board.

Because this connector is not keyed in any way, cards could be inserted
backwards, which would definitely be bad! For this reason, alignment marks
indicating Pin 1 are printed at Pin 1 on each slot as well as the cards
that plug into them.

The slots are spaced at 0.7", which is plenty of clearance for all currently
designed cards. If one card is taller than this, it can be placed in the
rightmost slot.

This backplane will cause the system to have a brick-like form factor
rather than the flattened all-in-one-keyboard design of v0, but the PCB
fabrication cost will be much cheaper since the layer count is halved.

If there is interest in keeping the design flat, I'm thinking of making a
backplane with right-angle connectors laid end-to-end, but again, it
would be significantly more expensive to fabricate.
```
layout

schematic

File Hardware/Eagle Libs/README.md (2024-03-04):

## Parts Library for Cadsoft Eagle v4.16r2

Never going to 'upgrade' this old workhorse. Oughta learn KiCad, though.

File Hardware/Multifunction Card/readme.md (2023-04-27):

# RASPBERRY PI PICO VERSION
(There's no firmware for this model yet.)

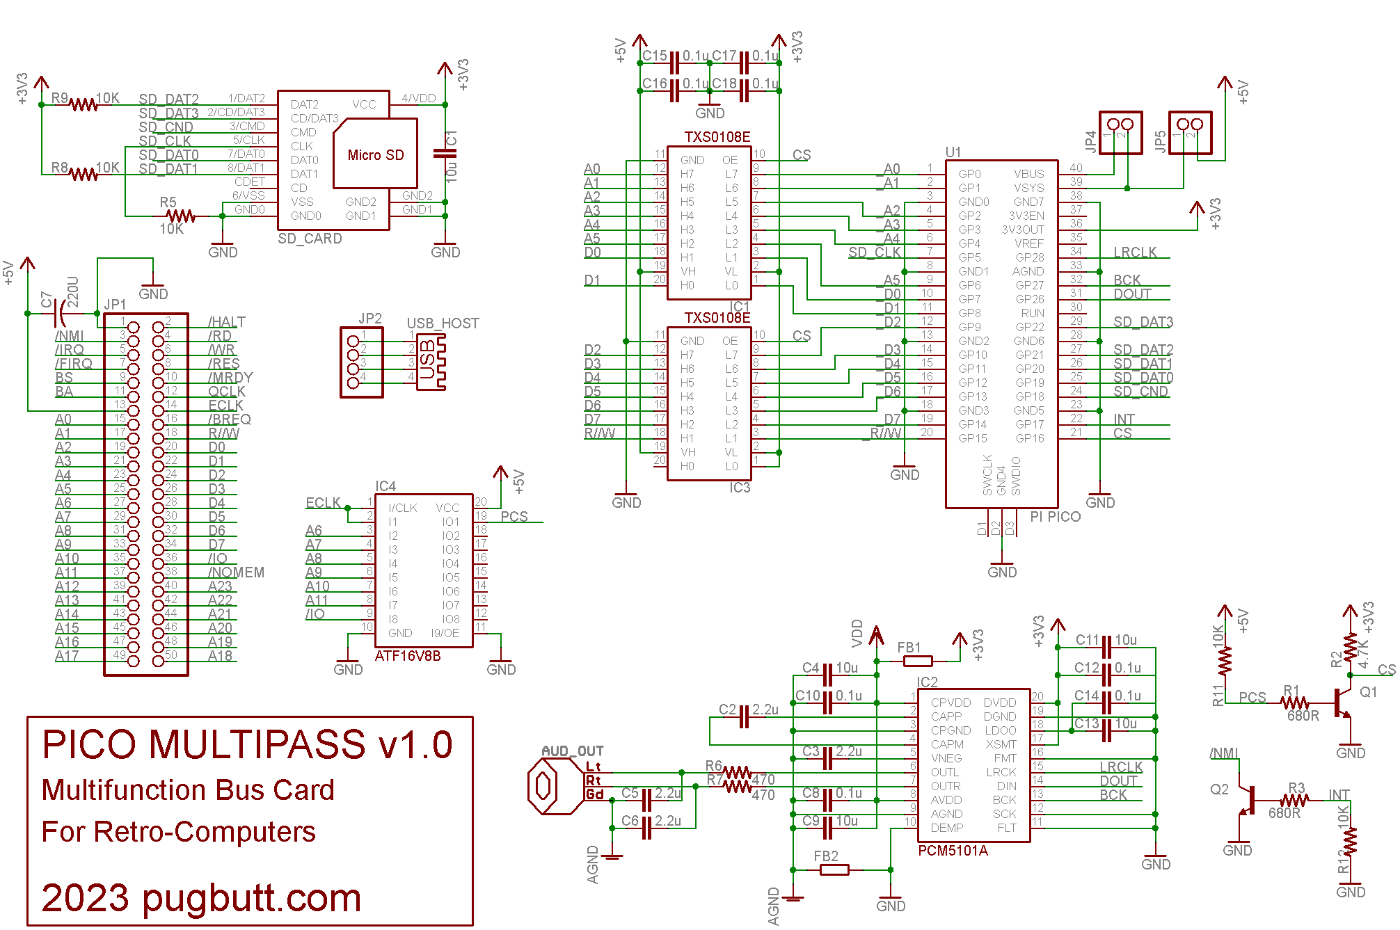
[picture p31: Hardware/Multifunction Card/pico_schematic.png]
Pico Schematic

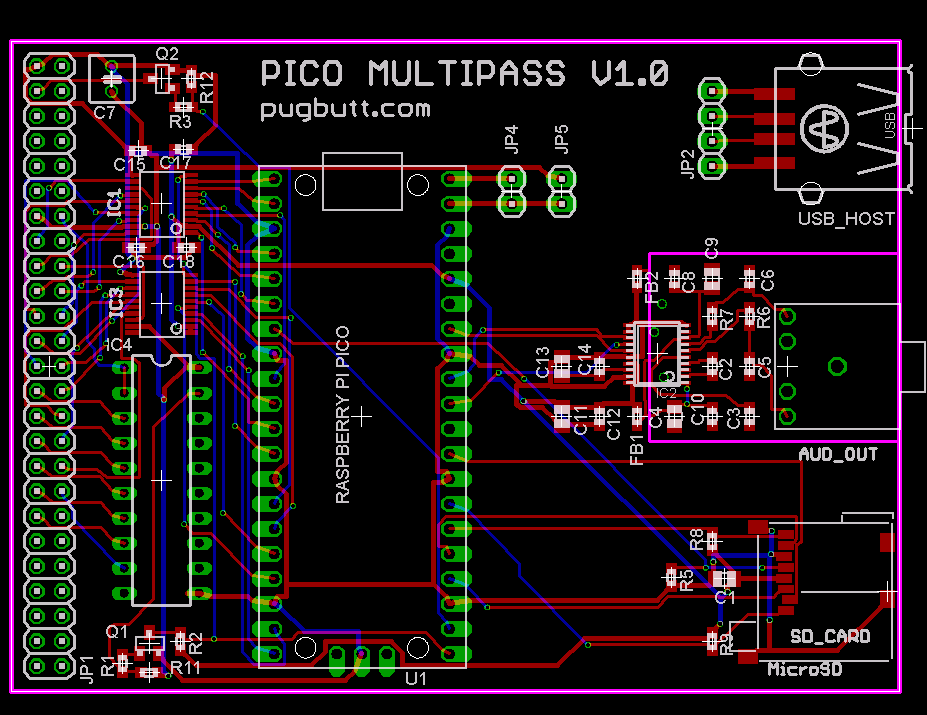
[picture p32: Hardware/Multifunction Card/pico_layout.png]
Pico Layout


# TEENSY VERSION
```
Currently in breadboard stange. It consists of the LV parallel 
interface card, available in the repo, connected to a 
Teensy 4.1 and sound board.

The Teensy 4.1 is connected to a parallel interface card with the 
following connections:

Parallel Card       Teensy Pin
-------------       ----------
VCC                 None
GND                 GND
+3V3                3v

CWR                 2
CRD                 3
UWR                 4
URD                 5

DB0                 28
DB1                 29
DB2                 30
DB3                 31
DB4                 32
DB5                 33
DB6                 34
DB7                 35

The partial firmware for the Teensy is an Arduino sketch provided
in /Software/Teensy 4.1/multipass

For information about the parallel interface signals and protocol,
see the README in the LV Parallel IO Card's directory.

```
# AVR Version
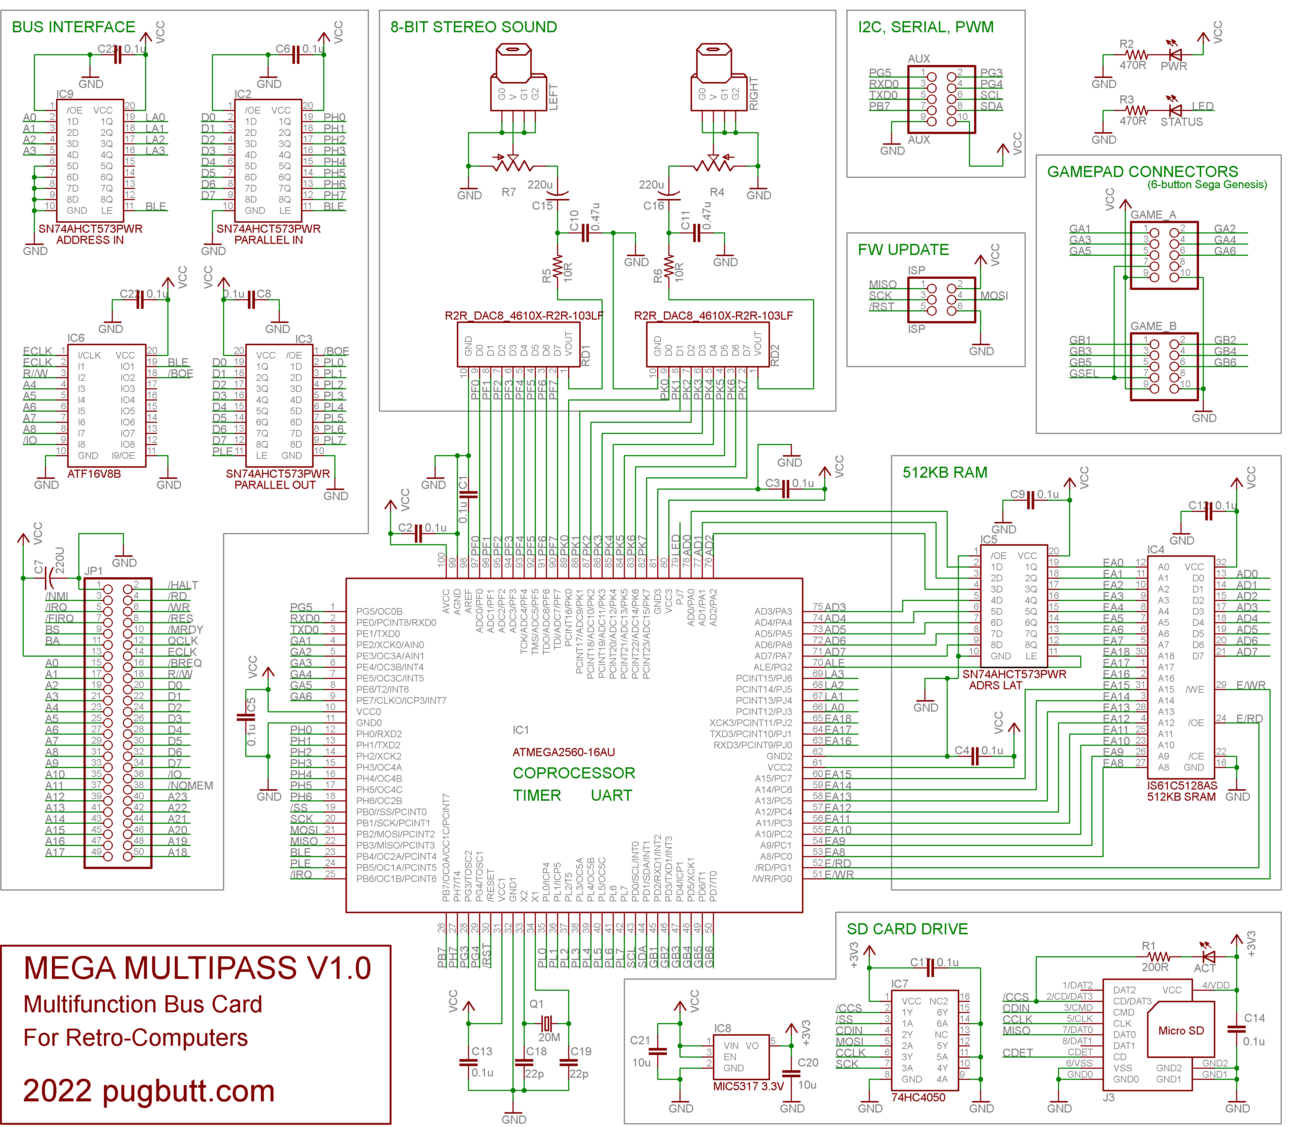
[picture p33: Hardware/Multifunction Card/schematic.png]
AVR Schematic

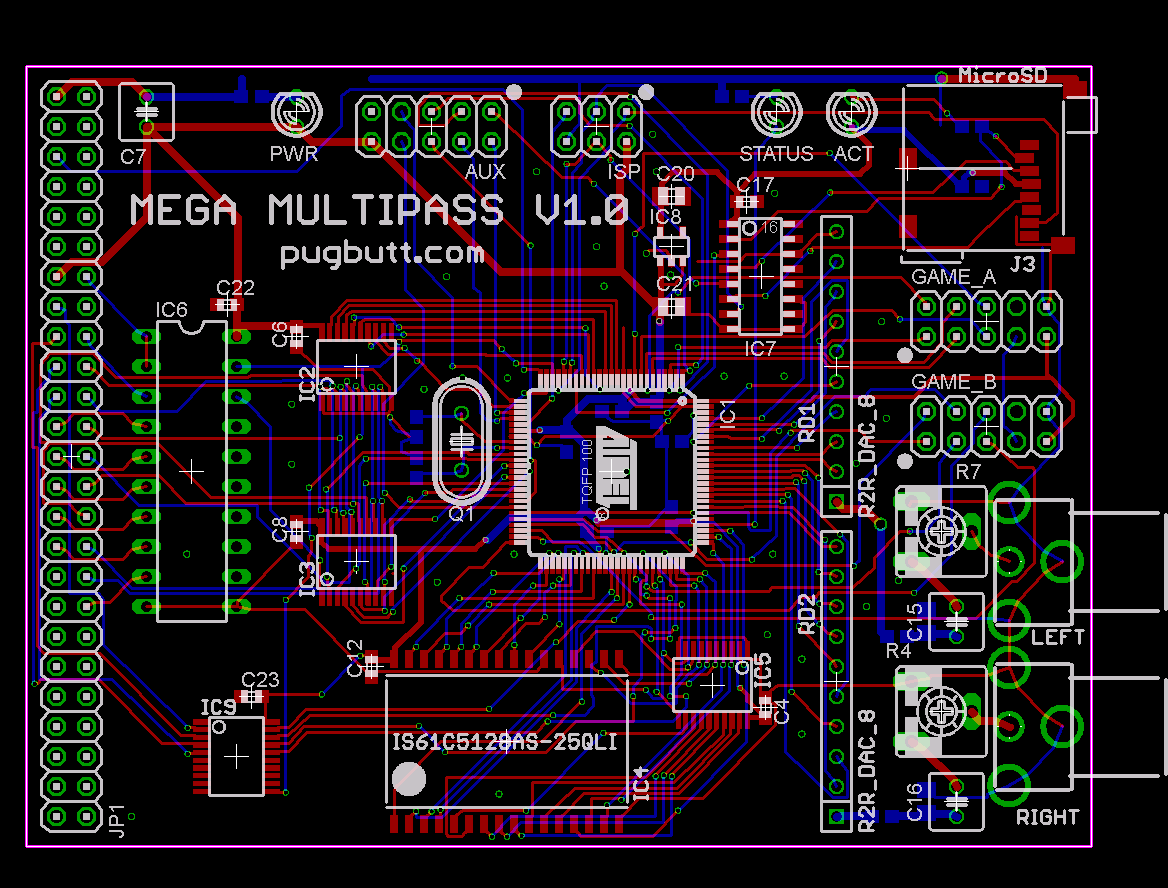
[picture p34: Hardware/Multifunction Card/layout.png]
AVR Layout


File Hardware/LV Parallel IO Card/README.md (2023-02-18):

```
*******************************************************************************

WHAT'S THE DIFFERENCE BETWEEN THIS LV PARALLEL CARD AND THE NON-LV ONE?

The LV Parallel Card uses three TXB0104 Bidirectional Level-Shifers for
interfacing the 5V CPU BUS with low-voltage (3.3V) peripherals such as Teensys
and Raspberry PI's.

If you want to interface to a 5V peripheral, such as an Arduino MEGA, use the 
other (NON-LV) Parallel Card!!

*******************************************************************************

Parallel bus interface and comms protocol

The parallel interface is implemented with a couple 8-bit latches and
a PLD, which intervene between the Teensy and the host CPU's data bus.

One latch is for data sent from CPU to Teensy, and the other is for data
sent from Teensy to CPU.

In addition to eight bidirectional data lines, db0...db7, there are
four handshake lines:

   CWR - CPU WRITE (Input,  Active High)
   CRD - CPU READ  (Input,  Active Low)
   UWR - MCU WRITE (Output, Active High)
   URD - MCU READ  (Output, Active Low)

   The function of these signals is further described below.

CPU TRANSMIT (Not a closed loop)

When the CPU writes a byte to the parallel card, the data is latched 
in the transmit latch by a rising edge on the CWR line. The Teensy can
see this signal, so it knows when a byte was written. The Teensy is
configured to fire a pin-change interrupt on a rising edge of CWR.
In the ISR (Interrupt handler), the Teensy will read out that byte:
first it enables the transmit latch output by setting the URD line
LOW, reads the value of signals db0...7db7, and finally, it sets URD
back to HIGH.

Currently, the CPU side is not made aware of a URD signal, but if we 
ever wanted to make transmission be a closed-loop (flow-controlled) 
operation, making the CPU aware of URD would be a good way. The Teensy 
is nice and fast though, so hopefully it should have no trouble keeping 
up with the reception of bytes from a vintage CPU anyway.

CPU RECEIVE (Closed loop)

The Teensy won't send bytes any faster than the CPU can read them. The 
way this is accomplished is as follows:

When the Teensy wants to write a byte, it presents the bits on db0...db7,
and it brings the UWR signal HIGH. This latches the bits in the receive 
latch, and it also begins an /IRQ state on the CPU side. 

In the CPU's IRQ ISR, it does a read of the parallel port byte, which
briefly causes a receive latch output enable signal (CRD) to go LOW.

The Teensy sees that CRD signal, and it fires a different pin-change 
interrupt on that falling edge. In the ISR, the Teensy returns it's UWR 
line back to LOW, which ends the /IRQ state on the CPU side. Until that
happens, the Teensy won't try to send any more bytes.

COMMUNICATIONS PROTOCOL

Bytes are sent through the interface as packets in the following format:

0xA5, 0x5A, u8 msg_type, u16 byte_cnt, u8 bytes[], u16 crc_ibm_bisync

where 0xA5, 0x5A are single bytes, byte_cnt is the number of bytes that
follow in the message, message types are described in defines.h, bytes[]
is an optional data payload, and CRC is a 16-bit CRC which uses a 
polynomial of value 0x8005. (This poly was used by IBM in the 1960's 
for their Bisync protocol.)

Not every message needs to have a data payload. In those cases, byte_cnt 
will equal 2, and there will be no data bytes prior to the CRC. The 
maximum payload size is 516 bytes. This is enough for 512-byte data with
a 32-bit byte-address value. This is for use when, e.g. transferring a 
file, in order to identify which part of the file is contained in the 
message. There is currently no provision for sending multiple files 
concurrently, but that might be accomplished by including some kind of 
file ID value in the message too.

Note that the vintage CPU that is currently being used in this project is
an HD6309 which uses BIG-ENDIAN byte ordering, so this protocol does too.
This means that an integer (16-bit, 32-bit value) is transmitted with 
the most significant byte first. For example, a byte count value of 256
would be sent as 0x01, 0x00. 

Some other CPU's, including AVR and Intel x86, use LITTLE-ENDIAN byte-
ordering, which is the opposite: the bytes of integers are stored with the
the least significant byte first, e.g. a value 0x1234 would be stored 
in memory and/or transmitted as 0x34 0x12. Historically, some ARM CPUs have 
been BI-ENDIAN, which means it is configurable which byte ordering is used, 
but in the Teensy, I expect it uses LITTLE-ENDIAN to maintain Arduino 
compatibility.  For this reason, if working with integers in the Teensy 
which have originated from the HD6309, including the CRC and byte_count of 
a received message, byte swapping may be involved when casting part of a 
byte array as an integer.
```

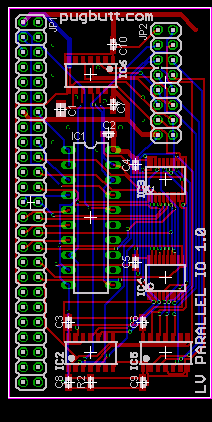
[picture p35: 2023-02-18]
Hardware/LV Parallel IO Card/LV Parallel IO Card Layout.png

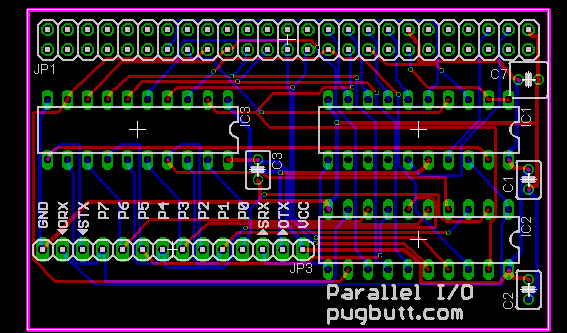
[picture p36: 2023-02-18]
Hardware/Parallel IO Card/Parallel IO Card Layout.png

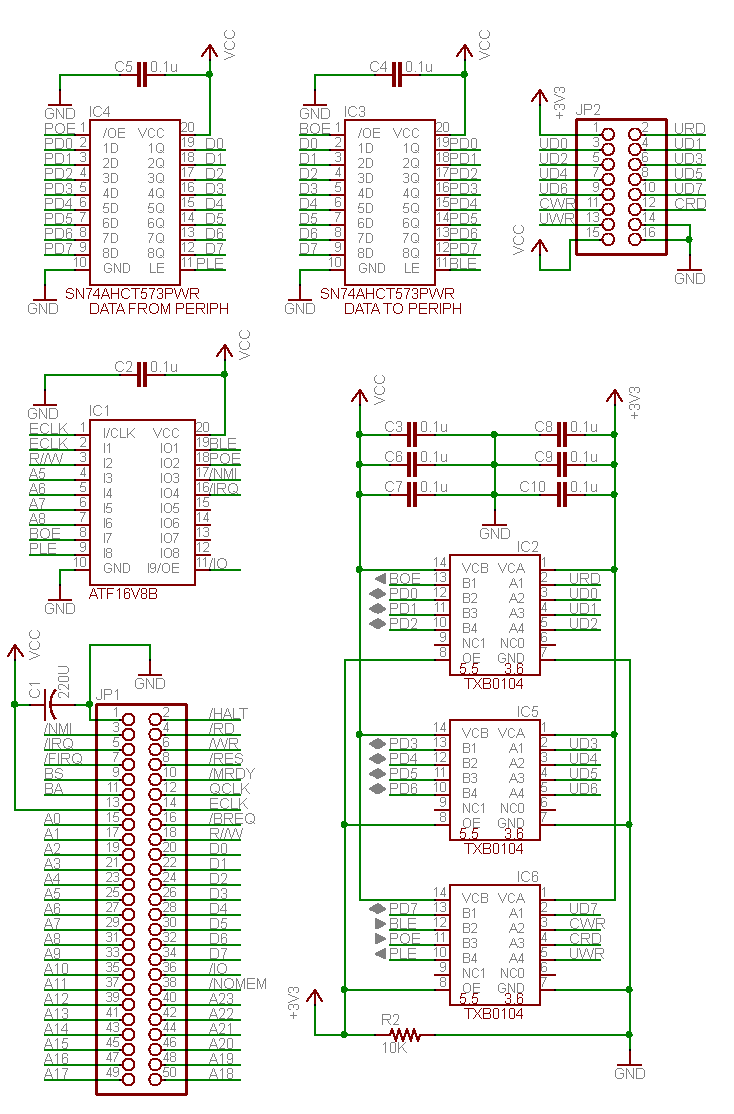
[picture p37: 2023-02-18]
Hardware/LV Parallel IO Card/LV Parallel IO Card Schematic.png

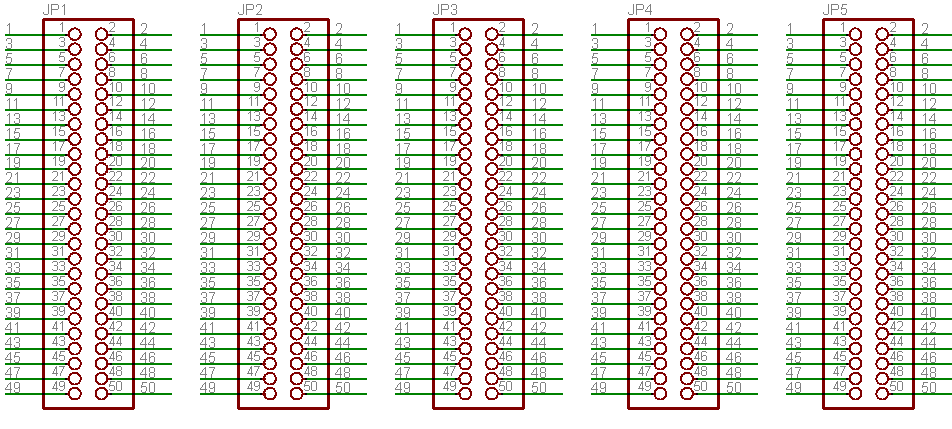
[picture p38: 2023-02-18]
Hardware/Backplane/v0/Backplane Schematic.png

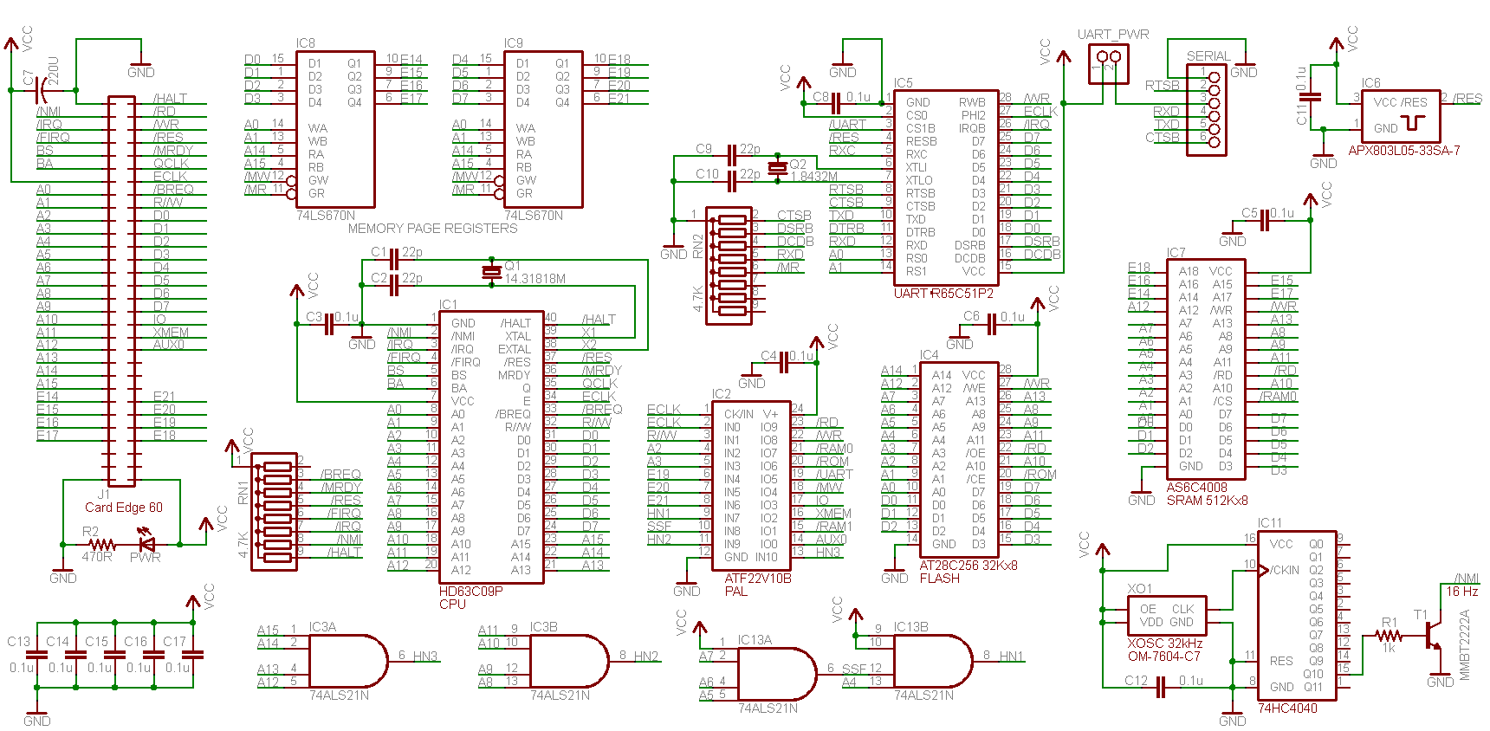
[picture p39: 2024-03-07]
Hardware/6309 CPU Card/experimental/schematic.png

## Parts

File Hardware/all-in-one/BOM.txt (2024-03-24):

Partlist

Exported from all_in_one_v2.sch at  3/24/2024 10:02:11a

EAGLE Version 4.16r2 Copyright (c) 1988-2006 CadSoft

Part     Value                       Device                          Package                         Library           Sheet

C1       22p                         C-EUC0603                       C0603                           rcl               1
C2       22p                         C-EUC0603                       C0603                           rcl               1
C3       0.1u                        C-EUC0603                       C0603                           rcl               1
C4       0.1u                        C-EUC0603                       C0603                           rcl               1
C5       0.1u                        C-EUC0603                       C0603                           rcl               1
C6       0.1u                        C-EUC0603                       C0603                           rcl               1
C8       0.1u                        C-EUC0603                       C0603                           rcl               1
C9       22p                         C-EUC0603                       C0603                           rcl               1
C10      22p                         C-EUC0603                       C0603                           rcl               1
C11      0.1u                        C-EUC0603                       C0603                           rcl               1
C12      0.1u                        C-EUC0603                       C0603                           rcl               1
C13      0.1u                        C-EUC0603                       C0603                           rcl               1
C14      0.1u                        C-EUC0603                       C0603                           rcl               1
C15      0.1u                        C-EUC0603                       C0603                           rcl               1
C16      0.1u                        C-EUC0603                       C0603                           rcl               1
C17      0.1u                        C-EUC0603                       C0603                           rcl               1
C18      0.1u                        C-EUC0603                       C0603                           rcl               1
C20      47u                         C-EUC0805                       C0805                           rcl               1
C21      22p                         C-EUC0603                       C0603                           rcl               1
C22      22p                         C-EUC0603                       C0603                           rcl               1
C23      0.1u                        C-EUC0603                       C0603                           rcl               1
C24      0.1u                        C-EUC0603                       C0603                           rcl               1
C25      0.1u                        C-EUC0603                       C0603                           rcl               1
C27      0.1u                        C-EUC0603                       C0603                           rcl               1
C28      0.1u                        C-EUC0603                       C0603                           rcl               1
C29      0.1u                        C-EUC0603                       C0603                           rcl               1
C30      0.01u                       C-EUC0603                       C0603                           rcl               1
C31      0.01u                       C-EUC0603                       C0603                           rcl               1
C32      47u                         C-EUC0805                       C0805                           rcl               1
C33      47u                         C-EUC0805                       C0805                           rcl               1
C34      220u                        C-EUC1206                       C1206                           rcl               1
C35      220u                        C-EUC1206                       C1206                           rcl               1
C36      220u                        C-EUC1206                       C1206                           rcl               1
C37      220u                        C-EUC1206                       C1206                           rcl               1
C38      220u                        C-EUC1206                       C1206                           rcl               1
C39      220u                        C-EUC1206                       C1206                           rcl               1
C40      0.1u                        C-EUC0603                       C0603                           rcl               1
C41      0.1u                        C-EUC0603                       C0603                           rcl               1
C42      5p                          C-EUC0603                       C0603                           rcl               1
C43      47p                         C-EUC0603                       C0603                           rcl               1
C44      330p                        C-EUC0603                       C0603                           rcl               1
C45      330p                        C-EUC0603                       C0603                           rcl               1
C46      330p                        C-EUC0603                       C0603                           rcl               1
C47      0.1u                        C-EUC0603                       C0603                           rcl               1
C48      0.1u                        C-EUC0603                       C0603                           rcl               1
C50      0.1u                        C-EUC0603                       C0603                           rcl               1
C51      0.1u                        C-EUC0603                       C0603                           rcl               1
C52      0.1u                        C-EUC0603                       C0603                           rcl               1
C53      0.1u                        C-EUC0603                       C0603                           rcl               1
C54      0.1u                        C-EUC0603                       C0603                           rcl               1
C55      0.1u                        C-EUC0603                       C0603                           rcl               1
C56      0.1u                        C-EUC0603                       C0603                           rcl               1
C57      220U                        C-US025-050X050                 C025-050X050                    rcl               1
C58      0.1u                        C-EUC0603                       C0603                           rcl               1
C59      0.1u                        C-EUC0603                       C0603                           rcl               1
C60      0.1u                        C-EUC0603                       C0603                           rcl               1
C61      22u                         C-EUC1206                       C1206                           rcl               1
C62      22u                         C-EUC1206                       C1206                           rcl               1
C63      22u                         C-EUC0805                       C0805                           rcl               1
C64      22p                         C-EUC0603                       C0603                           rcl               1
C65      22p                         C-EUC0603                       C0603                           rcl               1
C66      0.1u                        C-EUC0603                       C0603                           rcl               1
C67      0.1u                        C-EUC0603                       C0603                           rcl               1
C68      0.1u                        C-EUC0603                       C0603                           rcl               1
C69      0.1u                        C-EUC0603                       C0603                           rcl               1
C70      0.1u                        C-EUC0603                       C0603                           rcl               1
C71      0.1u                        C-EUC0603                       C0603                           rcl               1
D1       1N4148                      1N4148                          DO35-10                         diode             1
FB1                                  R-US_R0603                      R0603                           rcl               1
IC1      HD63C09P                    HD63C09P                        DIL40                           07-Retrocomputing 1
IC2      PLD_ATF22V10B               PLD_ATF22V10B                   DIL24-3                         07-Retrocomputing 1
IC3      74ALS21D                    74ALS21D                        SO14                            74xx-us           1
IC4      EEP_32KX8_AT28C256          EEP_32KX8_AT28C256              DIL28-6                         07-Retrocomputing 1
IC5      UART_W65C51N                UART_W65C51N                    DIL28-6                         07-Retrocomputing 1
IC6      POR_APX803L05-33SA-7        POR_APX803L05-33SA-7            SOT23                           07-Retrocomputing 1
IC7      PLD_ATF16V8B                PLD_ATF16V8B                    DIL20                           07-Retrocomputing 1
IC8      74LS670D                    74LS670D                        SO16                            74xx-us           1
IC9      74LS670D                    74LS670D                        SO16                            74xx-us           1
IC10     IS61C5128AS                 IS61C5128AS                     SOIC32_11.3MM_WID               07-Retrocomputing 1
IC11     74HC4040D                   74HC4040D                       SO16                            07-Retrocomputing 1
IC12     IS61C5128AS                 IS61C5128AS                     SOIC32_11.3MM_WID               07-Retrocomputing 1
IC13     74ALS21D                    74ALS21D                        SO14                            74xx-us           1
IC14     CXA2075M                    CXA2075M                        CXA2075M                        07-Retrocomputing 1
IC15     R1LP0408DSB-5SI#S1          R1LP0408DSB-5SI#S1              RENESAS_32-TSOP-II              07-Retrocomputing 1
IC16     SN74AHC574PWRSO             SN74AHC574PWRSO                 SOIC20                          07-Retrocomputing 1
IC17     YAMAHA_V9958                YAMAHA_V9958                    V9958                           07-Retrocomputing 1
IC18     74ALS04D                    74ALS04D                        SO14                            74xx-us           1
IC19     IS61C5128AS                 IS61C5128AS                     SOIC32_11.3MM_WID               07-Retrocomputing 1
IC20     IS61C5128AS                 IS61C5128AS                     SOIC32_11.3MM_WID               07-Retrocomputing 1
IC21     IS61C5128AS                 IS61C5128AS                     SOIC32_11.3MM_WID               07-Retrocomputing 1
IC22     IS61C5128AS                 IS61C5128AS                     SOIC32_11.3MM_WID               07-Retrocomputing 1
IC23     IS61C5128AS                 IS61C5128AS                     SOIC32_11.3MM_WID               07-Retrocomputing 1
IC24     IS61C5128AS                 IS61C5128AS                     SOIC32_11.3MM_WID               07-Retrocomputing 1
IC25     PLD_ATF16V8B                PLD_ATF16V8B                    DIL20                           07-Retrocomputing 1
IC26     W65C22S6TBG-14              W65C22S6TBG-14                  DIL40                           07-Retrocomputing 1
IC28     TXB0104D                    TXB0104D                        SOIC14                          07-Retrocomputing 1
IC29     MIC5317_3.3V                MIC5317_3.3V                    SOT23-5                         07-Retrocomputing 1
IC30     TXB0104D                    TXB0104D                        SOIC14                          07-Retrocomputing 1
IC31     TXB0104D                    TXB0104D                        SOIC14                          07-Retrocomputing 1
J2       XRGB                        MINI-DIN8                       MINI_DIN8                       07-Retrocomputing 1
J3       S-VIDEO                     MINI-DIN8                       MINI_DIN8                       07-Retrocomputing 1
J5                                   RCA_CONN_CUI_RCJ-014_CP-1403-ND RCA_JACK_CUI_RCJ-014_CP-1403-ND 07-Retrocomputing 1
J6                                   RCA_CONN_CUI_RCJ-014_CP-1403-ND RCA_JACK_CUI_RCJ-014_CP-1403-ND 07-Retrocomputing 1
J9       DCJ0202                     DCJ0202                         DCJ0202                         con-jack          1
J10      MICROSD_AMPHENOL_GTFP084328 MICROSD_AMPHENOL_GTFP084328     MICROSD_AMPHENOL_GTFP08432B1HR  07-Retrocomputing 1
JP1                                  PINHD-2X3                       2X03                            pinhead           1
JP2                                  PINHD-1X10                      1X10                            pinhead           1
JP3                                  PINHD-1X10                      1X10                            pinhead           1
JP4                                  PINHD-2X30                      2X30                            pinhead           1
MISC                                 PINHD-2X7                       2X07                            pinhead           1
PAR_IO                               PINHD-2X6                       2X06                            pinhead           1
PWR                                  LED3MM                          LED3MM                          led               1
Q1       14.31818M                   CRYSTALHC49S                    HC49/S                          crystal           1
Q2       1.8432M                     CRYSTALHC49S                    HC49/S                          crystal           1
Q3       21.47727M                   CRYSTALHC49S                    HC49/S                          crystal           1
Q4       12M                         CRYSTALHC49S                    HC49/S                          crystal           1
R1       1k                          R-US_R0603                      R0603                           rcl               1
R3       75R                         R-US_R0603                      R0603                           rcl               1
R4       75R                         R-US_R0603                      R0603                           rcl               1
R5       75R                         R-US_R0603                      R0603                           rcl               1
R6       43R                         R-US_R0603                      R0603                           rcl               1
R7       3.32K 1%                    R-US_R0603                      R0603                           rcl               1
R8       75R                         R-US_R0603                      R0603                           rcl               1
R9       75R                         R-US_R0603                      R0603                           rcl               1
R10      240R                        R-US_R0603                      R0603                           rcl               1
R11      4.7k                        R-US_R0603                      R0603                           rcl               1
R12      2k2                         R-US_R0603                      R0603                           rcl               1
R13      2k2                         R-US_R0603                      R0603                           rcl               1
R14      470R                        R-US_R0603                      R0603                           rcl               1
R15      470R                        R-US_R0603                      R0603                           rcl               1
R16      470R                        R-US_R0603                      R0603                           rcl               1
R17      4.7k                        R-US_R0603                      R0603                           rcl               1
R18      4.7k                        R-US_R0603                      R0603                           rcl               1
R19      75R                         R-US_R0603                      R0603                           rcl               1
R20      0R                          R-US_R0603                      R0603                           rcl               1
R23      470R                        R-US_R0603                      R0603                           rcl               1
R24      1k                          R-US_R0603                      R0603                           rcl               1
R25      0R                          R-US_R0603                      R0603                           rcl               1
R26      0R                          R-US_R0603                      R0603                           rcl               1
RN1      4.7K                        G08R                            SIL9                            resistor-sil      1
RN2      4.7K                        G08R                            SIL9                            resistor-sil      1
RN3                                  G08R                            SIL9                            resistor-sil      1
SERIAL                               PINHD-1X6                       1X06                            pinhead           1
T1       MMBT2222A                   MMBT2222ALT1-NPN-SOT23-BEC      SOT23-BEC                       transistor        1
U$2      PUG                         PUG                             LARGE_PUG                       07-Retrocomputing 1
U1       VREG_5V_VR10S05             VREG_5V_VR10S05                 VREG_5V_CP_POWER_VR10S05        07-Retrocomputing 1
U2       ATMEGA238PTQFP_             ATMEGA238PTQFP_                 TQFP32-08                       02_atmel          1
UART_PWR                             PINHD-1X2                       1X02                            pinhead           1
XO1      XODC_32KHZ_OM-7604-C7       XODC_32KHZ_OM-7604-C7           32K_XO_OM-7604-C7               07-Retrocomputing 1

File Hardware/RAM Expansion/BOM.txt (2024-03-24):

Partlist

Exported from 3MB RAM Expansion.brd at  3/24/2024 09:35:17a

EAGLE Version 4.16r2 Copyright (c) 1988-2006 CadSoft

Part     Value               Package             Library           Position (inch)       Orientation

C1       0.1u                C0603               rcl               (2.25 1.3125)         MR90
C2       0.1u                C0603               rcl               (2.25 2.125)          MR90
C3       0.1u                C0603               rcl               (3.625 1.3125)        MR90
C4       0.1u                C0603               rcl               (3.625 2.125)         MR90
C5       0.1u                C0603               rcl               (5 1.25)              MR90
C6       0.1u                C0603               rcl               (5 2.125)             MR90
C7       220U                C025-050X050        rcl               (0.175 0.55)          R180
C8       0.1u                C0603               rcl               (0.75 2.0625)         MR180
IC1      IS61C5128AS         SOIC32_11.3MM_WID   07-Retrocomputing (1.75 1.0625)         MR90
IC2      IS61C5128AS         SOIC32_11.3MM_WID   07-Retrocomputing (1.75 1.9375)         MR90
IC3      IS61C5128AS         SOIC32_11.3MM_WID   07-Retrocomputing (3.125 1.0625)        MR90
IC4      IS61C5128AS         SOIC32_11.3MM_WID   07-Retrocomputing (3.125 1.9375)        MR90
IC5      IS61C5128AS         SOIC32_11.3MM_WID   07-Retrocomputing (4.5 1.0625)          MR90
IC6      IS61C5128AS         SOIC32_11.3MM_WID   07-Retrocomputing (4.5 1.9375)          MR90
IC7      PLD_ATF16V8B        DIL20               07-Retrocomputing (0.675 1.45)          R270
J1       CARDEDGE_2.54_60POS CARDEDGE_2.54_60POS 07-Retrocomputing (1.5625 0)            R0
PWR                          LED3MM              led               (0.218752 2.3125)     R0
R2       470R                R0603               rcl               (0.375 2.375)         MR0
U$1      PUG                 LARGE_PUG           07-Retrocomputing (3.2625 1.075)        R0

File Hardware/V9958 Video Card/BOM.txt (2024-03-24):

Partlist

Exported from V9958 Video Card V2.brd at  3/24/2024 09:36:09a

EAGLE Version 4.16r2 Copyright (c) 1988-2006 CadSoft

Part     Value                   Package                         Library           Position (inch)       Orientation

C1       47u                     C0805                           rcl               (1.825 1.025)         MR0
C2       22p                     C0603                           rcl               (0.675 2.25)          MR180
C3       22p                     C0603                           rcl               (0.4625 2.25)         MR0
C4       0.1u                    C0603                           rcl               (0.8125 1.825004)     MR270
C5       0.1u                    C0603                           rcl               (0.35 0.875)          MR90
C6       5p                      C0603                           rcl               (3.75 1.9625)         MR0
C7       220u                    C025-050X050                    rcl               (0.2625 0.5125)       R90
C8       47p                     C0603                           rcl               (3.75 2.0625)         MR0
C9       330p                    C0603                           rcl               (3.6 1.5375)          MR0
C10      330p                    C0603                           rcl               (3.6 1.6875)          MR0
C11      330p                    C0603                           rcl               (3.6 1.8375)          MR0
C12      0.1u                    C0603                           rcl               (2.65 2.075)          MR90
C13      0.1u                    C0603                           rcl               (3.75 1.5875)         MR180
C14      0.1u                    C0603                           rcl               (3.75 1.6875)         MR180
C15      0.1u                    C0603                           rcl               (1.825 1.1)           MR0
C16      0.1u                    C0603                           rcl               (3.75 1.7875)         MR180
C17      0.01u                   C0603                           rcl               (4.15 1.5375)         MR180
C18      0.01u                   C0603                           rcl               (3.75 2.2375)         MR180
C19      47u                     C0805                           rcl               (0.125 0.5125)        MR90
C20      47u                     C0805                           rcl               (3.75 2.3125)         MR0
C21      47u                     C0805                           rcl               (4.15 1.4625)         MR0
C22      220u                    C1206                           rcl               (4.5 1.6375)          MR180
C23      220u                    C1206                           rcl               (4.5 1.7625)          MR180
C24      220u                    C1206                           rcl               (4.5 1.8875)          MR180
C25      220u                    C1206                           rcl               (4.5 2.1375)          MR180
C26      220u                    C1206                           rcl               (4.5 2.2375)          MR180
C27      0.1u                    C0603                           rcl               (1.6 1.375)           MR270
C28      220u                    C1206                           rcl               (4.5 1.5125)          MR180
C29      0.1u                    C0603                           rcl               (0.925 1.425)         MR270
C30      0.1u                    C0603                           rcl               (0.306248 1.581248)   MR270
FB1                              R0603                           rcl               (1.825 0.95)          MR180
IC1      YAMAHA_V9958            V9958                           07-Retrocomputing (1.55 1.575)          R0
IC2      PLD_ATF16V8B            DIL20                           07-Retrocomputing (0.95 0.75)           R0
IC3      74ALS04D                SO14                            74xx-us           (0.55 1.625)          MR180
IC9      CXA2075M                CXA2075M                        07-Retrocomputing (4.05 1.8875)         MR180
IC10     R1LP0408DSB-5SI#S1      RENESAS_32-TSOP-II              07-Retrocomputing (2.05 1.55)           MR270
IC11     SN74AHC574PWRSO         SOIC20                          07-Retrocomputing (1.225 1.55)          MR270
J1       XRGB                    MINI_DIN8                       07-Retrocomputing (5.5 1.406252)        R90
J2       S-VIDEO                 MINI_DIN8                       07-Retrocomputing (5.5 2.125)           R90
J3       CARDEDGE_2.54_60POSEDGE CARDEDGE_2.54_60POS             07-Retrocomputing (1.5625 0)            R0
J4                               RCA_JACK_CUI_RCJ-014_CP-1403-ND 07-Retrocomputing (5.125 0.843752)      R270
J5                               RCA_JACK_CUI_RCJ-014_CP-1403-ND 07-Retrocomputing (5.125 0.281252)      R270
JP2                              1X10                            pinhead           (3.6125 0.6125)       R270
JP3                              1X10                            pinhead           (4.5125 0.6125)       R270
PWR                              LED3MM                          led               (0.218752 2.3125)     R0
Q1       21.47727M               HC49/S                          crystal           (0.5625 2.15)         R0
R1       75R                     R0603                           rcl               (4.3375 1.5125)       MR180
R2       75R                     R0603                           rcl               (4.3375 1.6375)       MR180
R3       75R                     R0603                           rcl               (4.3375 1.7625)       MR180
R4       43R                     R0603                           rcl               (4.3375 1.8875)       MR180
R5       3.32K 1%                R0603                           rcl               (4.3375 2.0125)       MR180
R6       75R                     R0603                           rcl               (4.3375 2.1375)       MR180
R7       75R                     R0603                           rcl               (4.3375 2.2375)       MR180
R8       240R                    R0603                           rcl               (4.5 2.0125)          MR180
R9       2k2                     R0603                           rcl               (3.75 1.8875)         MR180
R10      4.7k                    R0603                           rcl               (0.6 1.325)           MR270
R11      2k2                     R0603                           rcl               (3.75 2.1625)         MR180
R12      470R                    R0603                           rcl               (3.6 1.6125)          MR0
R13      470R                    R0603                           rcl               (3.6 1.7625)          MR0
R14      470R                    R0603                           rcl               (3.6 1.9125)          MR0
R15      75R                     R0603                           rcl               (4.8625 1.0125)       MR0
R16      4.7k                    R0603                           rcl               (2.1875 0.875)        MR0
R17      4.7k                    R0603                           rcl               (2.375 0.875)         MR180
R18      0R                      R0603                           rcl               (3.218752 2.031252)   MR180
R19      470R                    R0603                           rcl               (0.1625 2.1375)       MR90
U$1      PUG                     LARGE_PUG                       07-Retrocomputing (3.387504 1.2875)     R0

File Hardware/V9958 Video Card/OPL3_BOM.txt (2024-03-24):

Partlist

Exported from opl3_module.brd at  3/24/2024 09:37:13a

EAGLE Version 4.16r2 Copyright (c) 1988-2006 CadSoft

Part     Value          Package       Library           Position (inch)       Orientation

C1       0.1u           C0603         rcl               (0.068748 0.675)      R270
C2       2700p          C0603         rcl               (0.9 0.7)             MR90
C3       2700p          C0603         rcl               (0.8 0.7)             MR90
C5       47p            C0603         rcl               (0.8 0.275)           MR270
C6       10u            C0805         rcl               (0.9 0.275)           MR270
FB1                     R0603         rcl               (0.125 0.4)           MR90
IC1      YMF262-M       YMF262_SOP24  07-Retrocomputing (0.425 0.5)           R270
IC2      14.31818M      XTAL_CSX-750F 07-Retrocomputing (0.9 0.5)             R270
IC3                     YAC512        07-Retrocomputing (0.375 0.5)           MR90
IC4      MC33074        SOIC14        07-Retrocomputing (0.85 0.5)            MR90
JP1                     1X10          pinhead           (0.55 0.95)           MR0
JP2                     1X10          pinhead           (0.55 0.05)           MR0
R1       33R            R0603         rcl               (0.631252 0.443748)   MR270
R3       10K            R0603         rcl               (0.9375 0.7)          R180

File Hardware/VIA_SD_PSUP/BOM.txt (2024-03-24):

Partlist

Exported from Via Card v2.brd at  3/24/2024 09:34:09a

EAGLE Version 4.16r2 Copyright (c) 1988-2006 CadSoft

Part     Value                       Package                        Library           Position (inch)       Orientation

C1       0.1u                        C0603                          rcl               (2.1875 1.375)        MR90
C2       0.1u                        C0603                          rcl               (0.625 0.875)         MR270
C3       0.1u                        C0603                          rcl               (2.5625 2.3125)       MR180
C4       22p                         C0603                          rcl               (4.125 1.375)         MR0
C5       22p                         C0603                          rcl               (4.125 1.125)         MR0
C6       22u                         C0805                          rcl               (3.7875 0.381248)     MR0
C7       220U                        C025-050X050                   rcl               (0.2 0.675)           R270
C8       22u                         C1206                          rcl               (4.25 0.5)            MR270
C9       22u                         C1206                          rcl               (4.25 0.25)           MR90
C10      0.1u                        C0603                          rcl               (3.156248 1.4375)     MR180
C11      0.1u                        C0603                          rcl               (3.156252 1.5625)     MR0
C12      0.1u                        C0603                          rcl               (3.875 1.5625)        MR270
C13      0.1u                        C0603                          rcl               (3.875 1.75)          MR270
C14      0.1u                        C0603                          rcl               (2.5375 1.675)        MR180
C15      0.1u                        C0603                          rcl               (2.5375 1.018748)     MR180
D1       1N4148                      DO35-10                        diode             (1.9875 2.0625)       R180
IC1      W65C22S6TBG-14              DIL40                          07-Retrocomputing (1.225 1.5375)        R0
IC2      PLD_ATF16V8B                DIL20                          07-Retrocomputing (1.1625 0.825)        R0
IC3      TXB0104D                    SOIC14                         07-Retrocomputing (2.65 2.043752)       MR0
IC4      MIC5317_3.3V                SOT23-5                        07-Retrocomputing (3.8125 0.275)        MR90
IC5      TXB0104D                    SOIC14                         07-Retrocomputing (2.6625 1.3875)       MR0
IC6      TXB0104D                    SOIC14                         07-Retrocomputing (2.65 0.731248)       MR0
J1       CARDEDGE_2.54_60POS         CARDEDGE_2.54_60POS            07-Retrocomputing (1.5625 0)            R0
J2       DCJ0202                     DCJ0202                        con-jack          (5.181248 0.325)      R90
J3       MICROSD_AMPHENOL_GTFP084328 MICROSD_AMPHENOL_GTFP08432B1HR 07-Retrocomputing (4.868752 1.156256)   MR270
JP3                                  2X03                           pinhead           (3.468748 0.9875)     R0
MISC                                 2X07                           pinhead           (5.05 2.0375)         R90
PAR_IO                               2X06                           pinhead           (0.9625 2.2)          R0
PWR                                  LED3MM                         led               (0.2125 2.324996)     R0
Q1       12M                         HC49/S                         crystal           (3.9375 1.25)         R90
R1       0R                          R0603                          rcl               (2.906248 2.218752)   MR0
R2       470R                        R0603                          rcl               (0.375 2.3125)        MR0
R3       1k                          R0603                          rcl               (0.875 1.6875)        MR270
R4       0R                          R0603                          rcl               (2.906252 1.875)      MR0
RN1                                  SIL9                           resistor-sil      (4.5 1.25)            R90
U$1      PUG                         LARGE_PUG                      07-Retrocomputing (2.8875 1.168752)     R0
U1       VREG_5V_VR10S05             VREG_5V_CP_POWER_VR10S05       07-Retrocomputing (4.5875 0.375)        R270
U2       ATMEGA238PTQFP_             TQFP32-08                      02_atmel          (3.5 1.5)             MR0

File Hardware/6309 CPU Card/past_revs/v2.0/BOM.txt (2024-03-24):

Partlist

Exported from 6309 CPU Card v2.brd at  3/24/2024 09:29:57a

EAGLE Version 4.16r2 Copyright (c) 1988-2006 CadSoft

Part     Value                 Package             Library           Position (inch)       Orientation

C1       22p                   C0603               rcl               (0.4375 2.156248)     MR270
C2       22p                   C0603               rcl               (0.25 2.156248)       MR270
C3       0.1u                  C0603               rcl               (0.781248 1.281252)   MR90
C4       0.1u                  C0603               rcl               (0.781248 2.293748)   MR90
C5       0.1u                  C0603               rcl               (2.968748 2.375)      MR0
C6       0.1u                  C0603               rcl               (4.218748 0.718752)   MR270
C7       220U                  C025-050X050        rcl               (0.175 0.55)          R180
C8       0.1u                  C0603               rcl               (4.593748 1.468752)   MR180
C9       22p                   C0603               rcl               (5.406248 0.406252)   MR0
C10      22p                   C0603               rcl               (5.406248 0.593748)   MR0
C11      0.1u                  C0603               rcl               (0.3125 1.531252)     MR90
C12      0.1u                  C0603               rcl               (2.468752 1.1875)     MR270
C13      0.1u                  C0603               rcl               (1.1875 0.5625)       MR270
C14      0.1u                  C0603               rcl               (1.75 0.5625)         MR270
C15      0.1u                  C0603               rcl               (2.343752 0.562504)   MR270
C16      0.1u                  C0603               rcl               (2.25 1.4375)         MR270
C17      0.1u                  C0603               rcl               (2.25 1.968752)       MR270
C18      0.1u                  C0603               rcl               (3.725 2.375)         MR0
IC1      HD63C09P              DIL40               07-Retrocomputing (1.125 1.4375)        R0
IC2      PLD_ATF22V10B         DIL24-3             07-Retrocomputing (1.4375 2.1875)       R0
IC3      74ALS21D              SO14                74xx-us           (2.5625 0.6875)       MR180
IC4      EEP_32KX8_AT28C256    DIL28-6             07-Retrocomputing (3.5625 0.875)        R180
IC5      UART_W65C51N          DIL28-6             07-Retrocomputing (4.75 0.8125)         R90
IC6      POR_APX803L05-33SA-7  SOT23               07-Retrocomputing (0.4375 1.5625)       MR180
IC8      74LS670D              SO16                74xx-us           (2 0.6875)            MR180
IC9      74LS670D              SO16                74xx-us           (1.4375 0.6875)       MR180
IC10     IS61C5128AS           SOIC32_11.3MM_WID   07-Retrocomputing (3.1875 1.875)        MR0
IC11     74HC4040D             SO16                07-Retrocomputing (2.5 1.5625)          MR180
IC12     IS61C5128AS           SOIC32_11.3MM_WID   07-Retrocomputing (3.95 1.875)          MR0
IC13     74ALS21D              SO14                74xx-us           (2.468752 2.093752)   MR180
J1       CARDEDGE_2.54_60POS   CARDEDGE_2.54_60POS 07-Retrocomputing (1.5625 0)            R0
PWR                            LED3MM              led               (0.218752 2.3125)     R0
Q1       14.31818M             HC49/S              crystal           (0.343748 2)          R0
Q2       1.8432M               HC49/S              crystal           (5.281248 0.5)        R270
R1       1k                    R0603               rcl               (2.375 1.3125)        MR270
R2       470R                  R0603               rcl               (0.375 2.375)         MR0
RN1      10K                   SIL9                resistor-sil      (0.625 0.8)           R180
RN2      10K                   SIL9                resistor-sil      (5.3125 1.25)         R90
SERIAL                         1X06                pinhead           (5.0625 2.093748)     R90
T1       MMBT2222A             SOT23-BEC           transistor        (2.3125 1.156252)     MR270
U$2      PUG                   LARGE_PUG           07-Retrocomputing (2.875 1.218752)      R0
UART_PWR                       1X02                pinhead           (4.443748 2.125)      R0
XO1      XODC_32KHZ_OM-7604-C7 32K_XO_OM-7604-C7   07-Retrocomputing (2.625 1.25)          MR0

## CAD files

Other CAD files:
3D_Models/backplane_100x.skp
3D_Models/cardedge_sys_v2.skp
3D_Models/cpu_card_100x.skp
3D_Models/keyboard_case.skp

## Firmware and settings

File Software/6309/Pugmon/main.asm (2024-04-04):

;------------------------------------------------------------------------------
; PROJECT: PUGMON 
; VERSION: 0.0.1
;    FILE: main.asm
;  AUTHOR: CRAIG IANNELLO, PUGBUTT.COM
;
; Description:
;
; PUGMON IS INTENDED TO BE A FULLY-FEATURED MACHINE-CODE MONITOR, DEBUGGER, 
; DISASSEMBLER, AND MINI ASSEMBLER FOR THE PUGBUTT INDUSTRIES PUGPUTER, A 
; SYSTEM BASED ON THE HITACHI HD63C09, A DESCENDENT OF THE MOTOROLA MC6809.
;
; RELEASED IN THE MID-1980'S, THE HD6309 WAS MARKETED AS 100% COMPATIBLE WITH
; THE MC6809, BUT AFTER A FEW YEARS, IT WAS DISCOVERED THAT THIS PART HAD SOME
; SECRET ENHANCEMENTS: IT CAN BE SWITCHED INTO "NATIVE MODE", WHICH OFFERS
; SIGNIFICANTLY FASTER EXECUTION SPEED, ADDITIONAL REGISTERS, AND NEW 
; INSTRUCTIONS SUCH AS MEMORY BLOCK-COPY AT 4X SPEED.
;
; I PLAN ON RUNNING THE HD6309 IN NATIVE MODE AT ALL TIMES, SO THIS UTILITY 
; WILL NOT WORK ON MC6809 SYSTEMS, FOR NOW ANYWAY.
;
; NOTES:
;
; PUGMON SUPPORTS TWO CONSOLE INTERFACES: A SERIAL PORT BASED ON THE ROCKWELL
; R65C51P2 UART, AT 19.2 KBAUD, AND A VIDEO DISPLAY BASED ON THE YAMAHA V9958.
; BECAUSE RAM IS CHEAP THESE DAYS, I'M IMPLEMENTING A FULL-SCREEN EDITOR,
; WITH ANSI CURSOR KEYS, REMINSCENT OF COMMODORE MACHINES, SO ONE WILL BE ABLE
; TO CURSOR-UP TO A LINE OF HEX-DUMP OR DISASSEMBLY AND CHANGE IT IN-SITU. 
; 
;------------------------------------------------------------------------------
    INCLUDE defines.d       ; Global settings and definitions
;------------------------------------------------------------------------------
; Module function imports
;------------------------------------------------------------------------------
; uart extern fcns
UT_INIT         EXTERN
; vdp Video Display Processor
VDP_COLDINIT    EXTERN
VDP_INIT        EXTERN
VDP_MODE_TEXT2  EXTERN
VDP_SHOW_PUG    EXTERN
VDP_CURS_STYLE  EXTERN

; parallel io
pa_init         EXTERN
pa_clear        EXTERN
pa_acknowledge  EXTERN
pa_service      EXTERN
pa_send_msg     EXTERN
PGotRxMsg       EXTERN
PFlags          EXTERN
PRxBuf          EXTERN
PRxHead         EXTERN
CrcVal          EXTERN
PMsgSize        EXTERN
PMsgEnd         EXTERN

; console
con_init        EXTERN
con_service     EXTERN
con_clrhome     EXTERN
con_puteol      EXTERN
con_getc        EXTERN
con_putc        EXTERN
con_puts        EXTERN
con_puthbyte    EXTERN
con_puthword    EXTERN
UT_PUTS         EXTERN
EndOfVars       EXTERN      ; provided by linker, this is the length of the bss              
                            ; section, which is also the start of USER RAM.
;------------------------------------------------------------------------------
; Functions exported for use by other modules
;------------------------------------------------------------------------------
JT_IRQ          EXPORT      ; ram jump table entry for IRQ vector
JT_FIRQ         EXPORT      ; ISR for FIRQ (vidio.asm)
JT_NMI          EXPORT
V_CBRK          EXPORT      ; Pseudo-ISR for when get CONTROL-C keypress
HEXBYTE         EXPORT
;------------------------------------------------------------------------------
BC_SWI      EQU  $00        ; One of these codes precede a stored break reg
BC_DZINST   EQU  $01        ; context to denote break type.
BC_CBRK     EQU  $02        ; control-c break
;------------------------------------------------------------------------------
; Zero page variables
;------------------------------------------------------------------------------
    SECT ram_start          ; Section address $0000 
;------------------------------------------------------------------------------
USER_RAM    RMB  2          ; STARTING ADDRESS OF FREE USER RAM
DP_WARM     RMB  1          ; IF NOT $55 ON RESET, WE DO A COLD START.
RAM_JTAB                    ; BEGIN RAM ISR JUMP TABLE ------------------------
JT_DZINST   RMB  3          ; DIVIDE BY ZERO OR ILLEGAL INSTRUCTION
JT_SW3      RMB  3          ; SWI 3 
JT_SW2      RMB  3          ; SWI 2 
JT_FIRQ     RMB  3          ; FIRQ 
JT_IRQ      RMB  3          ; IRQ 
JT_SWI      RMB  3          ; SWI
JT_NMI      RMB  3          ; NMI, END RAM JUMP TABLE -------------------------
;------------------------------------------------------------------------------
    ENDSECT
;------------------------------------------------------------------------------
; Misc Variables
;------------------------------------------------------------------------------
    SECT bss                ; Section Address $0018
;------------------------------------------------------------------------------
TMP_KEY     RMB  1          ; TEMP STORAGE OF MONITOR PROMPT KEYPRESS
DUMP_ADRS   RMB  2          ; ADDRESS USED BY HEXDUMP ROUTINE
EDUMP_ADRS  RMB  2          ; ENDING ADDRESS USED BY HEXDUMP ROUTINE
NEW_CTX     RMB  1          ; TRUE WHEN HAVE A NEW REGISTER CONTEXT TO SHOW
CTX_BUF     RMB  15         ; HOLDS MOST RECENT BREAK CONTEXT
LINBUF      RMB  256        ; BUFFER USED BY LINE EDITOR AND OUTPUT
STACK       RMB  512
STACKEND
;------------------------------------------------------------------------------
    ENDSECT
;------------------------------------------------------------------------------
    SECT code               ; Section address  $D000
;------------------------------------------------------------------------------
ANSI_CLS    FCB  ESCAPE
            FCC  "[2J"
            FCB  0
MSG_HELLO   FCB  LF,CR
            FCC  "PUGMON v0.0.1"  ; MESSAGE SHOWN ON COLD START
            FCB  LF,CR,0
BS_SWI      FCC  "<SWI>"    ; TAG SHOWN ON NORMAL (SWI) BREAK
            FCB  0     
BS_DZINST   FCC  "<DZI>"    ; TAG FOR ILLEGAL INSTRUCTION OR DIVIDE BY ZERO
            FCB  0                        
BS_CBRK     FCC  "<BRK>"    ; TAG FOR CONTROL-C BREAK
            FCB  0       

GETFILE_NAME FCC  "Float09.bin"
GETFILE_NAME_END

; this is a little example program that gets copied to RAM on startup
; in order to test the debugger:

E_MSG       FCC  "Hello, World!"
            FCB  0            
PRG_EXAMP   LDY  #E_MSG     ; EXAMPLE DBG PROG, LOADED TO RAM ON STARTUP
            JSR  con_puts   ; SHOW HELLO MESSAGE
            FCB  $15        ; ILLEGAL INSTRUCTION
            SWI             ; BREAK
END_EXAMP



; -----------------------------------------------------------------------------
; Interrupt Service Routines - RAM jump table is pointed to these at startup
; -----------------------------------------------------------------------------
V_NMI       RTI             ; NON MASKABLE INTERRUPT ISR - USED BY PARIO
V_SW3       RTI             ; SOFTWARE INTERRUPT 3 - UNUSED BY PUGMON
V_SW2       RTI             ; SOFTWARE INTERRUPT 2 - UNUSED BY PUGMON 
V_FIRQ      RTI             ; FIRQ ISR - USED IN VIDIO.ASM
V_IRQ                       ; IRQ ISR - THERES THREE IRQ HANDLERS:
                            ; UART TX/RX, AND THIS DEFAULT ONE.
            RTI             ; -------------------------------------------------

V_DZINST    LDA  #BC_DZINST ; DIVIDE BY ZERO, ILLEGAL INSTRUCTION ISR
            JMP  SAVE_CTX

V_SWI:      LDA  #BC_SWI    ; SOFTWARE INTERRUPT 1 (BREAKPOINT) ISR
SAVE_CTX    LDY  #CTX_BUF   ; IN BREAK CONTEXT BUFFER,
            STA  ,Y+        ; STORE BREAK TYPE CODE, 
            LDE  #14        ; WE UNSTACK THE CONTEXT MANUALLY, SINCE WE'RE
CTXLOOP     PULS A          ; STORING IT, AND WE'RE NOT DOING AN RTI AT THE
            STA  ,Y+        ; END OF THIS ISR.
            DECE            ; PULL ORDER: CC, A, B, E, F, DP, X, Y, U, PC
            BNE  CTXLOOP
            LDA  #1
            STA  NEW_CTX    ; NOTE WE HAVE A NEW REGISTER CONTEXT TO SHOW.
            JMP  MON_ENTRY  ; JUMP TO MONITOR PROMPT 
; -----------------------------------------------------------------------------
; ISR ROM JUMP-TABLE - GETS COPIED TO RAM DURING COLD-START, SO USER CAN 
; CUSTOMIZE ISRS WITHOUT NEEDING TO MODIFY THE ROM.
; -----------------------------------------------------------------------------
ROM_JTAB    JMP  V_DZINST   ; divide by zero, illegal instruction
            JMP  V_SW3      ;
            JMP  V_SW2      ;  
            JMP  V_FIRQ     ; vidio
            JMP  V_IRQ      ; serio
            JMP  V_SWI      ; monitor breakpoint
            JMP  V_NMI      ; pario
; -----------------------------------------------------------------------------
V_CBRK      LDA  #BC_CBRK   ; Pseudo-ISR. Called by serio when a CONTROL-C is
            JMP  SAVE_CTX   ; received.
; -----------------------------------------------------------------------------
; RESET VECTOR ENTRYPOINT
; -----------------------------------------------------------------------------
V_RESET     LDMD #$01       ; PROGRAM ENTRY-POINT - ENABLE 6309 NATIVE MODE 
            LDS  #$7fff     ; SET STACK TO END OF FIRST 32K OF RAM
            LDX  #EndOfVars ; start of user ram
            STX  USER_RAM   ; STORE THE STARTING ADRS OF USER RAM AT $0000
            LDA  DP_WARM    ; GET WARM START FLAG 
            CMPA #$55       ; IS IT A WARM START? 
            BEQ  WARMST     ; YES
COLDST      LDA  #$55       ; COLD START --------------------------------------
            STA  DP_WARM    ; DO A WARM START NEXT TIME. 
            LDX  #ROM_JTAB  ; COPY INTERRUPT JUMP TABLE FROM ROM TO RAM:
            LDY  #RAM_JTAB  ; 
            LDW  #(3*7)     ; 7 JMPS IS 21 BYTES
            TFM  X+,Y+      ; USING 6309'S NICE BLOCK COPY INSTRUCTION.
            CLR  NEW_CTX    ; No break register context to show yet
            JSR  con_init   ; init the console driver 
            JSR  pa_init    ; INIT PARALLEL PORT
            JSR  UT_INIT    ; INIT SERIAL PORT
            JSR  VDP_COLDINIT   ; Init video display, if present.
            JSR  VDP_SHOW_PUG

            ANDCC #$AF      ; ENABLE IRQ AND FIRQ INTERRUPTS            
            LDY  #ANSI_CLS  ; Clear serial terminal window
            JSR  UT_PUTS            
            LDY  #MSG_HELLO ; SHOW PUGMON TITLE BANNER
            JSR  con_puts
WARMST      LDX  #PRG_EXAMP ; WARM START --------------------------------------
            LDY  #$1000     ; COPY THE EXAMPLE PROGRAM TO RAM 
            LDW  #(END_EXAMP-PRG_EXAMP)
            TFM  X+,Y+    
            BRA  MON_ENTRY
; -----------------------------------------------------------------------------
; BREAK ENTRYPOINT TO MAINLOOP
; -----------------------------------------------------------------------------
MON_ENTRY   LDA  NEW_CTX    ; MONITOR ENTRYPOINT: CHECK IF GOT A REG CONTEXT --
            BEQ  MAINLOOP 
            CLR  NEW_CTX    ; GOT A NEW CTX TO SHOW
            ; TODO: IF VDP ISNT IN TEXT2 MODE, SWITCH TO TEXT2 MODE.
            ; MIGHT BE GOOD TO REMEMBER OLD MODE WHEN DOING THIS, SO IT CAN BE 
            ; RESTORED WHEN USER RESUMES EXECUTION AFTER A BREAK
            JSR  SHOW_CTX
; -----------------------------------------------------------------------------
; MAIN LOOP
; -----------------------------------------------------------------------------
MAINLOOP    JSR  con_service ; Console housekeeping service
ML_PAR      JSR  pa_service ; parallel port housekeeping service
            LDA  PGotRxMsg
            BEQ  ML_GETKEY
            JSR  show_pa    ; Show messages received via parallel
ML_GETKEY   JSR  con_getc   ; Check for keypress,
            BEQ  MAINLOOP   ; and loop until we get one. 
            CMPA #CR        ; IF WE GET A CR, ECHO IT, FOLLOWED BY A LF.
            BNE  ML_ECHO
            JSR  con_putc 
            LDA  #LF
            JSR  con_putc   
            BRA  MAINLOOP   ; done with cr/lf.
ML_ECHO     STA  TMP_KEY    ; STASH PRESSED KEY FOR FURTHER CHECKING, THEN
            JSR  con_putc   ; ECHO THE RECEIVED CHARACTER TO USER.
            LDA  TMP_KEY    ; DEPENDING ON KEY, MAYBE DO STUFF:
ML_K_CTL_L  CMPA #108       ; CTRL-L : CLEAR TEXT SCREEN AND CURSOR HOME
            BNE  ML_K_TIL
            JSR  con_clrhome    
ML_K_TIL    CMPA #TILDE     ; '~': RUN RAM EXAMPLE PROGRAM, THEN BREAK.
            BNE  ML_K_DIR
            JSR  con_puteol ; NEWLINE
            JMP  $1000
            BRA  MAINLOOP
ML_K_DIR    CMPA #'D        ; 'D': SEND DIR COMMAND VIA PARALLEL
            BNE  ML_K_GETFIL
            JSR  con_puteol
            LDA  #PAR_MSG_GET_DIR
            LDX  #0
            LDY  #0
            JSR  pa_send_msg
            BRA  MAINLOOP 
ML_K_GETFIL CMPA #'G        ; 'G': GET A BINARY FILE
            BNE  ML_K_STACK
            LDA  #PAR_MSG_GET_FILE  ; msg type
            LDX  #(GETFILE_NAME_END-GETFILE_NAME)  ; payload size
            LDY  #GETFILE_NAME      ; payload address
            JSR  pa_send_msg
            BRA  MAINLOOP             
ML_K_STACK  CMPA #'S        ; 'S': SHOW STACK PTR AS HEX
            BNE  ML_H_HEXDMP
            JSR  con_puteol
            TFR  S,D
            JSR  con_puthword
            JSR  con_puteol
            BRA  MAINLOOP             
ML_H_HEXDMP CMPA #'H        ; 'H': HEX DUMP 8K STARTING AT $8000
            BNE  ML_K_DUMP
            JSR  con_puteol
            LDX  #$8000
            STX  DUMP_ADRS
            LEAX 64,X
            STX  EDUMP_ADRS
            JSR  HEXDUMP_BLOCK            
            JMP  MAINLOOP
ML_K_DUMP   CMPA #'.        ; '.': Show parallel flags and buffer
            BNE  ML_K_TILES
            JSR  show_pa
            JMP  MAINLOOP
ML_K_TILES  CMPA #'T        ; 'T': GFX DRAW TILEMAP
            BNE  ML_K_FLOAT
            LDB  #0         ; DISABLE TEXT SCREEN AUTO-REFRESH
            JSR  VDP_MODE_TEXT2 
            JSR  $C012      ; SHOW TILEMAP
ML_TPAUSE   JSR  con_getc   ; WAIT FOR KEYPRESS
            BEQ  ML_TPAUSE
            JSR  VDP_INIT
            LDB  #1         ; RESUME TEXT SCREEN REFRESH
            JSR  VDP_MODE_TEXT2
            JMP  MAINLOOP
ML_K_FLOAT  CMPA #'M        ; 'M': GFX DRAW MANDEL
            BNE  ML_END
            LDB  #0         ; DISABLE TEXT SCREEN AUTO-REFRESH
            JSR  VDP_MODE_TEXT2 
            JSR  $C012      ; SHOW mandel
ML_TPAUSE2  JSR  con_getc   ; WAIT FOR KEYPRESS
            BEQ  ML_TPAUSE2
            JSR  VDP_INIT
            LDB  #1         ; RESUME TEXT SCREEN REFRESH
            JSR  VDP_MODE_TEXT2
            JMP  MAINLOOP
ML_END      JMP  MAINLOOP
; -----------------------------------------------------------------------------
; Show hexdump of received parallel message and some stats, and if it is a 
; freshly-received message, send an ACK so MCU knows we're ready for more.
; -----------------------------------------------------------------------------
PHDR        FCC  "GM FL  SZ  CRC"
            FCB  LF,CR,0
    
show_pa:    LDA  (PRxBuf+2)  ; get message type
            CMPA #PAR_MSG_DUMPTEXT
            BEQ  mode_text
            CMPA #PAR_MSG_DUMPTEXTEND
            BEQ  mode_text
mode_binary LDY  #PHDR      ; print header
            JSR  con_puts
            LDA  PGotRxMsg  ; 1: new valid message
            JSR  con_puthbyte
            LDA  PFlags     ; parallel debug flags
            JSR  con_puthbyte        
            LDD  PMsgSize   ; parallel rx message size
            JSR  con_puthword
            LDD  CrcVal     ; CRC-16 (0 for valid message)
            JSR  con_puthword
            JSR  con_puteol
            LDX  #PRxBuf    ; Hex dump of message bytes
            STX  DUMP_ADRS
            TFR  X,W
            ADDW PMsgSize
            TFR  W,X
            STX  EDUMP_ADRS
            JSR  HEXDUMP_BLOCK
            LDA  PGotRxMsg  ; If newly received message,
            BEQ  spa_done
            JSR  pa_acknowledge ; Send ack to MCU.            
spa_done    RTS
mode_text   LDX  #(PRxBuf+5)  ; text dump of message bytes
            STX  DUMP_ADRS
            TFR  X,W
            ADDW PMsgSize
            SUBW #7
            TFR  W,X
            STX  EDUMP_ADRS
            JSR  TEXTDUMP_BLOCK
            LDA  PGotRxMsg  ; If newly received message,
            BEQ  spa_done
            JSR  pa_acknowledge ; Send ack to MCU.            
            RTS            

; -----------------------------------------------------------------------------
; Show latest saved register context from a monitor break 
; -----------------------------------------------------------------------------
CTX_HDR     FCB  LF,CR      ; BREAK REGISTER CONTEXT HEADER
            FCC  "  CC A  B  E  F  DP  X    Y    U    PC"
            FCB  LF,CR,0

SHOW_CTX    LDX  #LINBUF            
            LDY  #CTX_BUF    
            LDF  ,Y+        ; GET BREAK TYPE IN F
            BEQ  BT_SW
            CMPF #BC_CBRK
            BNE  BT_DZ
BT_CB       LDY  #BS_CBRK   ; CODE 2: CONTROL-C BREAK: <CBK>
            BRA  BT_HDR
BT_DZ       LDY  #BS_DZINST ; CODE 3: DIV 0 OR ILLEGAL INSTRUCTION BREAK <DZI>
            BRA  BT_HDR
BT_SW       LDY  #BS_SWI    ; CODE 0: SOFTWARE INTERRUPT 1 BREAK <SWI>
BT_HDR      BSR  STRCPY
            LEAX ,-X        ; REMV NULL
            LDY  #CTX_HDR   ; e.g. "  CC A  B  E  F  DP  X    Y    U    PC "
            BSR  STRCPY     ;      "; A5 00 0C 00 00 00 00A9 E07D FFFF 1008"
            LEAX ,-X        ; REMV NULL
            LDA  #';        ; PRECEED EDITABLE REG VALUES WITH A ';'
            STA  ,X+
            LDY  #CTX_BUF+1    
            LDE  #6
CTX_BYTE    LDA  #SPACE     ; DO CC, A, B, E, F, DP
            STA  ,X+
            LDA  ,Y+
            BSR  HEXBYTE
            DECE
            BNE  CTX_BYTE
            LDE  #4
CTX_WORD    LDA  #SPACE     ; DO X, Y, U, PC  
            STA  ,X+
            LDA  ,Y+
            BSR  HEXBYTE
            LDA  ,Y+
            BSR  HEXBYTE
            DECE
            BNE  CTX_WORD
            BSR  TEXTTERM   ; ADD CR+LF+NULL TO OUTPUT STRING
            LDY  #LINBUF
            JSR  con_puts   ; OUTPUT CTX STRING TO CONSOLE
            RTS             ; END REG CONTEXT PRINT 
;------------------------------------------------------------------------------
TEXTTERM    LDA  #CR        ; ADD CR+LF+NULL TO MEMORY AT X 
            STA  ,X+
            LDA  #LF
            STA  ,X+
            LDA  #0
            STA  ,X+
            RTS
;------------------------------------------------------------------------------
HEXBYTE:                    ; CONVERTS VAL IN A TO 2 HEX BYTES AT X 
            TFR  A,B        ; SAVE ORIGINAL BINARY VALUE
            LSRA            ; MOVE HIGH DIGIT TO LOW DIGIT
            LSRA
            LSRA
            LSRA
            CMPA #9
            BLS  AD30       ; BRANCH IF HIGH DIGIT IS DECIMAL
            ADDA #7         ; ELSE ADD 7 SO AFTER ADDING 'O' THE
                            ; CHARACTER WILL BE IN ‘'A'..'F'
AD30:       ADDA #'0        ; ADD ASCII O TO MAKE A CHARACTER
            ANDB #$0F       ; MASK OFF LOW DIGIT
            CMPB #9
            BLS AD3OLD      ; BRANCH IF LOW DIGIT IS DECIMAL
            ADDB #7         ; ELSE ADD 7 SO AFTER ADDING 'O! THE
                            ; CHARACTER WILL BE IN '‘A'..'F!
AD3OLD:     ADDB #'0        ; ADD ASCII O TO MAKE A CHARACTER
            STA ,X+         ; INSERT HEX BYTES INTO DEST STRING AT X
            STB ,X+         ; AND NCREMENT X
            RTS 
;------------------------------------------------------------------------------
STRCPY      LDA  ,Y+        ; COPY Y TO X, INCLUDING NULL TERMINATOR. 
            STA  ,X+
            BNE  STRCPY
            RTS
;------------------------------------------------------------------------------
HEXDUMP_LINE:               ; DUMPS 16 BYTES OF MEMORY AS HEX/ASCII VIA UART 
            LDX  #LINBUF
            LDA  #'>        ; PUT '>' BEFORE ADDRESS
            STA  ,X+
            LDA  DUMP_ADRS  ; THEN 4-CHAR HEX ADDRESS
            BSR  HEXBYTE
            LDA  DUMP_ADRS+1
            BSR  HEXBYTE
            LDA  #32        ; THEN A SPACE,
            STA  ,X+
            LDY  DUMP_ADRS  ; GET STARTING ADDRESS IN Y
            LDE  #16        ; FOR 16 ITERATIONS
            LDU  #(LINBUF+1+5+16*3)  ; POINT U AT ASCII PART AFTER HEX CHARS
            LDA  #$A8       ; WHICH BEGINS WITH THIS AS A DELIMITER
            STA  ,U+
            LDF  #'.

HEXLOOP     CMPY EDUMP_ADRS ; IF PASS THE END DUMP ADRS, STOP SHOWING HEX
            BGE  NULLOOP
            LDA  ,Y+        ; GONNA SHOW A HEXBYTE
            CMPA #32
            BGE  ASCIIOK
            STF  ,U+        ; SHOW ASCII NONPRINTABLES AS A DECIMAL POINT
            BRA  DONEASCII
ASCIIOK     STA  ,U+        ; ADD ASCII CHAR OR DEC TO LINE AT POS U
DONEASCII   BSR  HEXBYTE    ; AT LINE POS X, ADD 2-CHAR HEX BYTE AND
            LDA  #32        ; A SPACE,
            STA  ,X+
            DECE            ; CHECK IF MORE BYTES TO DO
            BNE  HEXLOOP
            BRA  LINEDONE

NULLOOP     LDA  ,Y+        ; PAST EDUMP ADRS, SHOW NOTHING
            LDA  #32
            STA  ,U+        
            STA  ,X+
            STA  ,X+
            STA  ,X+
            DECE            ; CHECK IF MORE BYTES TO DO
            BNE  NULLOOP
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

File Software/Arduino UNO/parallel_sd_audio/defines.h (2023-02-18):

///////////////////////////////////////////////////////////////////////////////
// Project-wide settings and definitions
///////////////////////////////////////////////////////////////////////////////
#ifndef __DEFINES_H__
#define __DEFINES_H__
// ----------------------------------------------------------------------------
#include <stdint.h> // for data types such as uint8_t, int16_t, etc.
#include <Arduino.h>
// ----------------------------------------------------------------------------
#define DEBUG   // comment out if you dont want verbose serial debug log

extern char ts[32];   // general purpose temp string

// ----------------------------------------------------------------------------
// Serial debug logger --------------------------------------------------------
#define   SER_BAUD              115200
// SD card stuff --------------------------------------------------------------
// Uses the default (HW) SPI pins, plus the following chip select:
#define   SD_CS                 10
// Parallel bus interface -----------------------------------------------------
#define   PAR_BUF_SZ            256+11 //(512+11)// Max message buffer size
#define   PAR_CRC_POLY          0x8005  // CRC polynomial - IBM Bisync

// ARDUINO UNO CONNECTIONS
#define   PAR_PIN_CWR           2       // in - CPU write byte (active high)
#define   PAR_PIN_CRD           3       // in - CPU read byte (active low)
#define   PAR_PIN_URD           4       // out - MCU read byte (active low)
#define   PAR_PIN_UWR           5       // out - MCU write byte (active high)
#define   PAR_PIN_D0            A0      // I/O - Data bit 0
#define   PAR_PIN_D1            A1      // I/O - Data bit 1
#define   PAR_PIN_D2            A2      // I/O - Data bit 2
#define   PAR_PIN_D3            A3      // I/O - Data bit 3
#define   PAR_PIN_D4            A4      // I/O - Data bit 4
#define   PAR_PIN_D5            A5      // I/O - Data bit 5
#define   PAR_PIN_D6            6       // I/O - Data bit 6
#define   PAR_PIN_D7            7       // I/O - Data bit 7

/*
// TEENSY 4.1 CONNECTIONS
#define   PAR_PIN_CWR           2       // in - CPU write byte (active high)
#define   PAR_PIN_CRD           3       // in - CPU read byte (active low)
#define   PAR_PIN_UWR           4       // out - MCU write byte (active high)
#define   PAR_PIN_URD           5       // out - MCU read byte (active low)
#define   PAR_PIN_D0            28      // I/O - Data bit 0
#define   PAR_PIN_D1            29      // I/O - Data bit 1
#define   PAR_PIN_D2            30      // I/O - Data bit 2
#define   PAR_PIN_D3            31      // I/O - Data bit 3
#define   PAR_PIN_D4            32      // I/O - Data bit 4
#define   PAR_PIN_D5            33      // I/O - Data bit 5
#define   PAR_PIN_D6            34      // I/O - Data bit 6
#define   PAR_PIN_D7            35      // I/O - Data bit 7
*/
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

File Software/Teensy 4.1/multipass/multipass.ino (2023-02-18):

///////////////////////////////////////////////////////////////////////////////
//
//  MEGA MULTIPASS - Teensy 4.1 as a Retrocomputer Peripheral - v0.0.1
//  
//      This project allows the Teensy to be interfaced to 
//      classic retrocomputers to potentially provide 
//      several services:
//
//        * SD card file system
//        * Audio IN/OUT/SYNTH
//        * Misc IO (SPI, I2C, UART, USB, PS/2)
//        * Programmable Timers
//        * Coprocessor, math, crypto, etc.
//        * ???
//
//  Communications with the host system is via a bidirectional parallel 
//  interface attached to the computer's data bus. It uses a lightweight, 
//  message-based protocol with error-checking. For more info on how that 
//  works, see "parallel.h"
//
//  Note, the counterpart of this project on the 6309 side is project Pugmon,
//  module pario.asm. (I expect to add more relevant modules to pugmon soon,
//  e.g. fileio.asm, soundio.asm, kbio.asm, gpio.asm, etc.)  
//
//  Also,I'm hoping to eventually make use of these modules from Extended BASIC
//  and other languages, probably by doing 'system calls' to the Pugmon ROM.
//  
///////////////////////////////////////////////////////////////////////////////
#include <SD.h>
#include "defines.h"      // project settings, gpio pin assignments
#include "parallel.h"     // host cpu bus interface
#include "audio.h"
#include "usb_kb.h"
// ----------------------------------------------------------------------------
void setup()
{
  // Init serial debug port
  Serial.begin(SER_BAUD);
  while (!Serial);

  Serial.println("Initializing Services...");
  
  Serial.print("    Parallel bus Interface...");  
  par_init();   // parallel bus interface 
  
  Serial.print("    SD card filesystem...");  
  sd_init();    // sd card
  
  Serial.print("    Audio IO...");  
  aud_init();   // audio

  Serial.print("    USB Keyboard...");  
  ukb_init();   // usb keyboard
  
  Serial.println("\nInit complete. Have a very safe day.\n");
  sei();
}
// ----------------------------------------------------------------------------
// Main loop does housekeeping calls to some peripherals.
// ----------------------------------------------------------------------------
void loop()
{
  aud_service();
  par_service();  
  ukb_service();
  

  // todo: dispatch requests made my CPU via parallel

  // par_send_dir_blocking("/");
  //par_send_file_blocking("Float09.bin");
  //par_send_file_blocking("mandel.hex");

}

///////////////////////////////////////////////////////////////////////////////
//
// SD Card stuff is below.
// 
// I would like to move this stuff to a separate source file,
// but that causes compilation to fail!!?   WTF!!?!?!!
//
///////////////////////////////////////////////////////////////////////////////

// change this to match your SD shield or module;
// Teensy 2.0: pin 0
// Teensy++ 2.0: pin 20
// Wiz820+SD board: pin 4
// Teensy audio board: pin 10
// Teensy 3.5 & 3.6 & 4.1 on-board: BUILTIN_SDCARD

const int chipSelect = BUILTIN_SDCARD;

// ----------------------------------------------------------------------------
void par_send_file_blocking(char * fname)
{
  uint8_t buf[256];

  sprintf(buf,"*** Sending file \"%s\"...",fname);
  Serial.println((char *)buf);
  
  File dataFile = SD.open(fname);
  uint32_t i = 0;
  uint32_t m = 0;
  if (dataFile) 
  {
    par_file_tx_start();
    while (dataFile.available()) 
    {
      uint16_t sz = dataFile.readBytes(buf,256);
      par_file_tx_update(buf,sz,false);
    }
    par_file_tx_update(0,0,true);
    dataFile.close();
  }  
  else 
  {
    Serial.println("error opening file");
    par_send_message(MSG_NCOMP,0,0);
  }   
}
// ----------------------------------------------------------------------------
void par_send_dir_blocking(char * dirname)
{
   char lbuf[256];
   char b[32];

   sprintf(lbuf,"*** Sending directory of \"%s\"...",dirname);
   Serial.println(lbuf);
   
   File dir = SD.open(dirname);
   par_file_tx_start();
   bool didone = false;
   while(true) 
   {
     File entry = dir.openNextFile();
     if (! entry)
     {
       if (!didone)
       {
         par_send_message(MSG_NCOMP,0,0);
         return;
       }
       break;
     }
     didone = true;
     DateTimeFields datetime;
     if (entry.getModifyTime(datetime)) 
     {
       printTime(datetime,lbuf);
       strcat(lbuf," ");
     }
     if (entry.isDirectory()) 
       strcat(lbuf,"      --- ");
     else
     {
       sprintf(b,"%9d ",entry.size());
       strcat(lbuf,b);
     }  
     strcat(lbuf,entry.name());
     if (entry.isDirectory()) 
       strcat(lbuf,"/");
     strcat(lbuf,"\n");
     Serial.print(lbuf);
     par_file_tx_update(lbuf,strlen(lbuf),false);
     entry.close();
   }
   par_file_tx_update(0,0, true);
}
// ----------------------------------------------------------------------------
void sd_init()
{
  //Uncomment these lines for Teensy 3.x Audio Shield (Rev C)
  //SPI.setMOSI(7);  // Audio shield has MOSI on pin 7
  //SPI.setSCK(14);  // Audio shield has SCK on pin 14  
  if (!SD.begin(chipSelect)) 
  {
    Serial.println(" FAIL!!");
    return;
  }
  Serial.println(" OK.");
}
// ----------------------------------------------------------------------------
void printTime(const DateTimeFields tm, char * s) 
{
  s[0]=0;
  char b[20];  
  sprintf(b,"%04d",tm.year + 1900);
  strcat(s,b);
  strcat(s,"-");
  sprintf(b,"%02d",tm.mon);
  strcat(s,b);
  strcat(s,"-");
  sprintf(b,"%02d",tm.mday);
  strcat(s,b);
  strcat(s," ");
  sprintf(b,"%02d",tm.hour);
  strcat(s,b);
  strcat(s,":");
  sprintf(b,"%02d",tm.min);
  strcat(s,b);  
}
// ----------------------------------------------------------------------------
// EOF
// ----------------------------------------------------------------------------

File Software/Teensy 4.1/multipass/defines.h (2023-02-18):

// ----------------------------------------------------------------------------
//
//  MEGA MULTIPASS - Teensy 4.1 as a Retrocomputer Peripheral
//  
//  Project-wide definitions, settings, and includes.
//
// ----------------------------------------------------------------------------
#ifndef __DEFINES_H__
#define __DEFINES_H__
// ----------------------------------------------------------------------------
#include <stdint.h>
#include <Arduino.h>
// ----------------------------------------------------------------------------

// Serial debug logger --------------------------------------------------------

#define   SER_BAUD                  115200

// Parallel Bus Interface -----------------------------------------------------

// Handshake Lines

#define   PIN_CWR                   2
#define   PIN_CRD                   3
#define   PIN_UWR                   4
#define   PIN_URD                   5

// Parallel Interface Data IO lines (db0...db7)

#define   PIN_DB0                   28
#define   PIN_DB1                   29
#define   PIN_DB2                   30
#define   PIN_DB3                   31
#define   PIN_DB4                   32
#define   PIN_DB5                   33
#define   PIN_DB6                   34
#define   PIN_DB7                   35

// Message types

#define MSG_STATUS            0     // when sent: no payload, response: t_status
#define MSG_GET_DIR           1     // payload when sent: null-terminated path, or nothing.
                                    // text-format dir is returned in one or more MSG_DUMP messages.
#define MSG_DUMP              2     // payload is 4-byte address or byte idx,
                                    // followed by up to 512 bytes of data.
#define MSG_DUMPEND           3     // same as above, but denotes final dump msg of xfer
#define MSG_CHDIR             4     // payload: null-terminated path, or ".."
                                    // returns an ack or NAK
#define MSG_KBHIT             5     // payload is one or more kbdown & kbup codes 

#define MSG_NAK               253   // crc failed on prev message from you
#define MSG_ACK               254   // acknowledge
#define MSG_NCOMP             255   // couldnt comply with request

// Error flag bits that may be set in g_errors -------------------------------
#define   ERR_TX_BUF_FULL           1   // cpu not handling tx bytes fast enough
#define   ERR_RX_BUF_FULL           2   // not handling rx bytes fast enough
#define   ERR_PAR_HOST_NO_RESPONSE  4   // cpu isnt reading the bytes we sent
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

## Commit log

2023-02-18 initial commit
    initial commit
    [6309 CPU Card v0.brd, 6309 CPU Card v0.sch, Backplane.brd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]
2023-02-18 wedge 3d model and graphics
    [keyboard_case.skp]
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2023-02-28 add scart pin 16 (mode) voltage to xrgb connector
    [V9958 Video Card.brd, V9958 Video Card.sch]
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2023-03-25 label the opl3 synth chip and DAC
    might be useful to know WHICH CHIPS it uses! haha
    [opl3_module.sch]
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2023-04-27 add raspberry pi pico version
    [megacard_atmega.brd, megacard_atmega.sch, megacard_pipico.brd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]
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2023-05-08 picostuff and cpu card v1
    [6309 CPU Card v1.brd, 6309 CPU Card v1.sch, megacard_pipico.brd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]
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2023-05-08 cpu card v1
    address decoder should now allow io space to be where I want it!!
    [6309 CPU Card v1.brd, 6309 CPU Card v1.sch]
2023-05-08 Update 6309 CPU Card v1.brd
    [6309 CPU Card v1.brd]
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2024-02-19 pugmon cleanup video/console code, improve video card
    [LV Parallel IO Card.sch, V9958 Video Card V2.brd, V9958 Video Card V2.sch]
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2024-03-01 new cpu board with banked memory and RTC
    [6309 CPU Card Edge.brd, 6309 CPU Card Edge.sch]
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2024-03-01 rename cpu card v2
    [6309 CPU Card v2.brd, 6309 CPU Card v2.sch]
2024-03-02 update cpu card v2
    [6309 CPU Card v2.brd, 6309 CPU Card v2.sch]
2024-03-02 Board ordered from Oshpark
    [6309 CPU Card v2.brd, 6309 CPU Card v2.sch]
2024-03-02 cleanup cpu card folder, move v0 to past_revs
    [6309 CPU Card v0.brd, 6309 CPU Card v0.sch]
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2024-03-03 work-in-progress sd card / io / psup card
    [Via Card v2.brd, Via Card v2.sch]
2024-03-03 WIP: SD, GPIO, Power Supply card
    [Via Card v2.brd, Via Card v2.sch]
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2024-03-03 Update Via Card v2.sch
    [Via Card v2.sch]
2024-03-03 change cpu card form factor
    [6309 CPU Card v3.brd, 6309 CPU Card v3.sch]
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2024-03-03 via card form factor
    [Via Card v2.brd, Via Card v2.sch]
2024-03-03 add diode needed for VIA-S /IRQ
    [Via Card v2.brd, Via Card v2.sch]
2024-03-03 add atmega328 to via board
    [Via Card v2.brd, Via Card v2.sch]
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2024-03-03 cpu card form factor
    [6309 CPU Card v2.brd, 6309 CPU Card v2.sch]
2024-03-03 via board form factor
    [Via Card v2.brd, Via Card v2.sch]
2024-03-03 via card needed more pug
    [Via Card v2.brd, Via Card v2.sch]
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2024-03-03 v9958 video vard v2 form factor
    [V9958 Video Card V2.brd, V9958 Video Card V2.sch]
2024-03-04 silk labels on some ports
    [6309 CPU Card v2.sch, V9958 Video Card V2.brd, Via Card v2.brd]
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2024-03-04 add uart power jumper
    [6309 CPU Card v2.brd, 6309 CPU Card v2.sch]
2024-03-04 update vid card title font
    [V9958 Video Card V2.brd]
2024-03-04 vid card connect GND and AGND through ferrite bead
    [V9958 Video Card V2.brd, V9958 Video Card V2.sch]
2024-03-04 ferrite to jumper link
    [V9958 Video Card V2.brd, V9958 Video Card V2.sch]
2024-03-04 fix decoder bug, add gate delay and power led
    [V9958 Video Card V2.brd, V9958 Video Card V2.sch]
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2024-03-04 resize backplane, add registration marks
    [6309 CPU Card v2.brd, Backplane.brd, Backplane.sch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]
2024-03-05 cardedge has some fingers needing holes to be flush
    [Backplane.brd, Backplane.sch]
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2024-03-05 Move realtime interrupt from IRQ to NMI (edge sensitive)
    [6309 CPU Card v2.brd, 6309 CPU Card v2.sch]
2024-03-05 backplane layout hide bottom text
    [Backplane.brd]
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2024-03-06 consistent placement of PWR LED
    [6309 CPU Card v2.brd, V9958 Video Card V2.brd, Via Card v2.brd]
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2024-03-07 mostly through-hole cpu board experiment
    [6309 CPU Card v2.brd, 6309 CPU Card v2.sch, Backplane.brd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]
2024-03-07 experimental thru hole cpu board
    [6309 CPU Card v2.brd, 6309 CPU Card v2.sch]
2024-03-07 cpu card add pld code
    [6309 CPU Card ordered.brd, 6309 CPU Card ordered.sch]
2024-03-08 connect ground plane of backplane
    [Backplane.brd]
2024-03-08 gnd plane bug dangit
    [Backplane.brd, Backplane.sch]
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2024-03-20 brighter power LEDs (max for red, med for white)
    [3MB RAM Expansion.brd, 3MB RAM Expansion.sch, 6309 CPU Card v2.brd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]
2024-03-23 power led's were way too bright at full current
    [3MB RAM Expansion.brd, 3MB RAM Expansion.sch, 6309 CPU Card v2.brd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]
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2024-03-30 wrong signal on UART
    [6309 CPU Card v2.brd, 6309 CPU Card v2.sch]
2024-03-30 AIO fix uart bug, eliminate bigger GAL
    [all_in_one_v2.brd, all_in_one_v2.sch]
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2024-03-31 AIO beautifying? Also, had a thru-hole IC on the bottom!?
    [all_in_one_v2.brd, all_in_one_v2.sch]
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2024-04-02 add power switch and add bank register /oe signal to bus conn
    [6309 CPU Card v2.brd, 6309 CPU Card v2.sch, Via Card v2.brd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]
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2024-04-08 aio fix bug
    [all_in_one_v2.brd, all_in_one_v2.sch]
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2024-04-12 fixed horrible chip-killiing bug! (+5V VREG was backwards)
    [Via Card v2.brd, Via Card v2.sch]
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2024-04-14 via card add mcu reset to misc conn for fw update
    [Via Card v2.brd, Via Card v2.sch]
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2024-05-16 correct sd card wiring
    [Via Card v2.brd, Via Card v2.sch]
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2024-05-19 via card swap io ports
    [Via Card v2.brd, Via Card v2.sch]
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2024-09-23 The music synthesizer works!
    I wish I could say the same for the video. :-(
    [6309 CPU Card v2.brd, 6309 CPU Card v2.sch, Via Card v2.brd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]
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2025-02-15 Update footprint of cardedge to add 0.6mm gap between fingers and board edge.
    [6309 CPU Card v2.brd, 6309 CPU Card v2.sch]
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2025-02-26 via card was on /NMI rather than /IRQ!
    [Via Card v2.brd, Via Card v2.sch]
2025-02-27 via card add pullups on maybe disconnected port
    [Via Card v2.brd, Via Card v2.sch]
2026-09-03 Document voltage regulator mishap in README
    Added a note about a voltage regulator issue that caused damage to the board.
2026-09-03 Document voltage regulator issue in README
    Updated README to reflect issues with the voltage regulator and potential board replacement.
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2026-09-30 Complete RP2350B video card
    This is the new video card, as emulated in the emulator. It lacks the vintage street-cred, but it is much more capable. Also the old Yamaha V9958 is getting more rare an expensive.
    [pico2_video.brd, pico2_video.sch]
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2026-11-06 Video card bring-up: SD-select timing, faster renderer, clean bus start
    GAL (VIDCARD.PLD revision 02): SDCS is now decoded from A7-A2 alone.
    Qualified with /IO, it rose at the same moment /VCS fell, and the card
    often read the register index before SD-select arrived, so SD accesses
    were taken as video registers' and the boot from SD failed at random.
    With revision 02 no access's index changes after /CS falls.
    Firmware:
    - bus.pio: WAIT GPIO uses the absolute pin number (CS_N 32; 16 waited
    on a DVI pin). bus_events takes the index and a write's data as /CS
    rises, and keeps the index as /CS fell for the diagnostics.
    - bus.c: the level shifters go on before the state machines start, and
    t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
2026-11-09 Video card: gamepad button maps, PSRAM timing, faster tiles
    Gamepads report standard buttons, translated through a map by USB
    VID:PID: 8 maps the 6309 can write, then a built-in list (SN30 Pro).
    Read-only VID, PID and raw buttons at $040060. PADMAP, on the disk
    image, sets maps up and saves them to /CMD/PADMAP.INI.
    PSRAM: psram_configure_params only stores the timing, so the chip
    stayed at the boot divider (168 MHz, rated 133). psram_reinitialize
    applies it (112 MHz); this fixed TILEKIT's map undo on hardware.
    Renderer: 4-bit tile and 8-bit sprite rows folded per scale and flip,
    and whole tiles drawn in runs that reuse a repeated map entry and skip
    empty rows. TILEKIT's three layers of 8x8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
2026-11-09 Video card: faster 640x480 tiles; TILEKIT with a blank tile 0 on disk
    640x480 4-bit tile rows now draw from the pair tables the sprites use,
    a byte's two pixels in one load and one store. On hardware, three solid
    layers at 640x480 went from 88 to 73 us a line, with minor jitter.
    Diag: the report re-times the live picture on each core, alone and
    together, and shows each core's mean line time and the layer modes.
    The startup bench is off unless built with VIDCARD_BENCH=1, for RAM.
    The disk image has TILEKIT with tile 0 kept blank.
2026-11-09 console in/out on kbd/vidcard if present
    can still run just the CPU card with UART-only console, but if bios detects the vid/usb card, everything moves to display & keyboard, and the cpu card's uart just shows a banner and error reports
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
